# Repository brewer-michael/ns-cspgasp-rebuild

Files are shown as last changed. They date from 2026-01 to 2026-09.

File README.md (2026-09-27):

# Open Speaker

**An open-source rebuild of the Insignia NS-CSPGASP smart speaker: a voice
assistant and alarm clock for Home Assistant, with speech recognition and AI models
on your own network. Its brain is an ESP32-S3 or a Raspberry Pi Zero 2 W.**

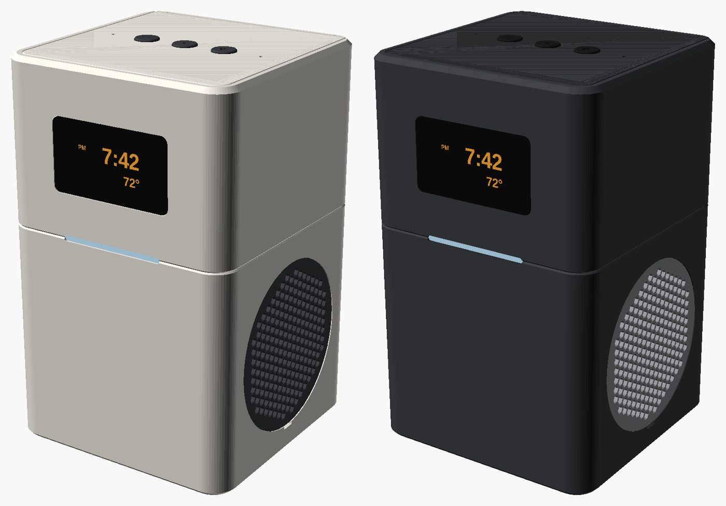
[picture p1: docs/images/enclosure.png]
Open Speaker, light and dark


Google stopped supporting the NS-CSPGASP's Assistant board, and its hardware is
locked down. This project keeps only the two speaker drivers and replaces
everything else with parts you can buy anywhere, in a 3D-printed enclosure on the
original's footprint.

- **Voice control through Home Assistant**: "Okay Nabu, turn off the kitchen
  lights".
- **Your models, on your network**: Whisper or Speech-to-Phrase for speech
  recognition, Ollama, llama.cpp or any OpenAI-compatible server for the
  conversation, Piper or Kokoro for the voice. Nothing leaves your home unless
  you choose a cloud service.
- **Light on the speaker**: only the wake word (microWakeWord) runs on the speaker.
  Speech recognition runs elsewhere.
- **A clock first**: the display always shows the time and temperature, like the
  original, and the alarm rings even when the network is down.
- **Stereo**, two MAX98357A amplifiers into the original drivers, in a tuned
  bass chamber.
- **Physical buttons** for volume, talk/stop/snooze and microphone mute. Status
  light in the waist.

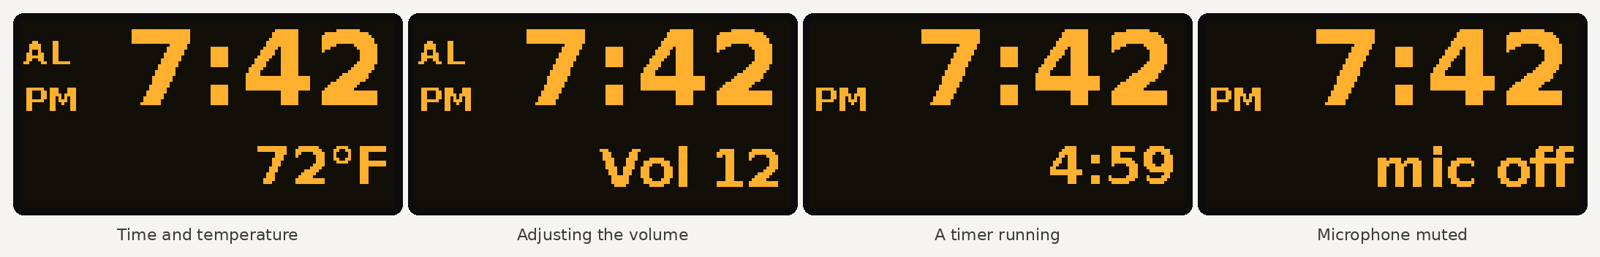
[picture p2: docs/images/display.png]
The clock face: time, AL/PM, and the temperature slot showing the temperature, the volume, a timer or "mic off"


## How it works

```
 Open Speaker                                      your network
 ┌──────────────────────────────┐
 │ 2 × INMP441 mics ─► wake word │   voice    ┌──────────────────────────────┐
 │ (microWakeWord)               │ ─────────► │ Home Assistant Assist pipeline│
 │                               │            │  (Pi: or your own servers):   │
 │ clock, alarm, volume,         │   reply    │  speech-to-text  (Whisper)    │
 │ mute: on the speaker          │ ◄───────── │  language model  (Ollama)     │
 │                               │            │  text-to-speech  (Piper)      │
 │ 2 × MAX98357A ─► 2 drivers    │            └──────────────────────────────┘
 │ OLED clock, LEDs, buttons     │ ◄── Home Assistant automations
 └──────────────────────────────┘
```

## Two brains

Everything except the brain is the same: drivers, amplifiers, microphones, display,
LEDs, buttons, enclosure and wiring. Pick one:

| | ESP32-S3 (default) | Raspberry Pi Zero 2 W |
|---|---|---|
| Board | ESP32-S3-DevKitC-1-N8R8, $15 | Pi Zero 2 WH and a microSD card, about $27 |
| Software | ESPHome: [`esphome/`](esphome/) | The `open-speaker` Linux service: [`firmware/`](firmware/) |
| Needs Home Assistant | Yes | No: it can also talk to your speech and AI servers directly |
| Timers and alarms | Timers by voice through Home Assistant; the alarm clock rings from the speaker's clock | Handled on the speaker, by voice, even when the network is down |
| Automations | ESPHome entities and actions | An HTTP API |
| Availability | Easy to buy | Often out of stock in 2026 |

The ESP32-S3 is the default because you can buy it everywhere and it is the
simplest to run. The Pi does more on its own.

## Hardware

| | |
|---|---|
| Brain | ESP32-S3-DevKitC-1 or Raspberry Pi Zero 2 W |
| Audio out | 2 × MAX98357A I2S class-D amplifiers, 3 W each, into the original 4 Ω drivers |
| Audio in | 2 × INMP441 I2S MEMS microphones |
| Display | 1.3" 128 × 64 OLED (on the Pi also a 2.42" OLED or a TM1637 7-segment display) |
| Controls | 4 tactile buttons, 3 WS2812B status LEDs |
| Power | 5 V 3 A over USB-C |
| Enclosure | 100 × 100 × 160 mm, PETG, no supports; ported bass chamber |

About $75 in parts per speaker with the ESP32-S3 ($87 with the Pi), or about $215
for the first one, because many parts come in packs: see the
[bill of materials](docs/BOM.md), with a link for every part. To shop, open
[docs/shopping-list.html](docs/shopping-list.html) in a browser.

## Getting started

1. **Build**: [docs/ASSEMBLY_GUIDE.md](docs/ASSEMBLY_GUIDE.md): teardown, wiring,
   testing on the desk, enclosure.
2. **Install**:
   - ESP32-S3: flash it with ESPHome, see [esphome/README.md](esphome/README.md).
   - Pi: on Raspberry Pi OS Lite (64-bit):

     ```sh
     git clone -b v2 https://github.com/brewer-michael/ns-cspgasp-rebuild.git
     sudo ns-cspgasp-rebuild/scripts/install.sh
     ```

3. **Connect**: [Home Assistant](docs/HOME_ASSISTANT.md). On the Pi, you can also
   use [your own speech and AI servers](docs/LOCAL_AI.md) directly;
   `sudo open-speaker doctor` checks the whole setup.

## Repository

| Path | |
|---|---|
| [`esphome/`](esphome/) | The ESP32-S3 brain: ESPHome configuration and sounds |
| [`firmware/`](firmware/) | The Raspberry Pi brain: the `open-speaker` Python package and its tests |
| [`hardware/enclosure/`](hardware/enclosure/) | Parametric OpenSCAD enclosure, export script |
| [`hardware/schematics/gpio_pinout.md`](hardware/schematics/gpio_pinout.md) | Wiring for both brains |
| [`hardware/speaker_specs/`](hardware/speaker_specs/) | Measuring the salvaged drivers |
| [`scripts/`](scripts/) | Installer for the Pi, and checks that keep the docs and sounds in step |
| [`config/`](config/) | ALSA, boot configuration and systemd unit (used by the installer) |
| [`server/`](server/) | Docker Compose for Whisper, Piper and Ollama |
| [`docs/`](docs/) | Build guide, BOM and shopping list, Home Assistant and local AI guides |
| [`insignia_ns_cspgasp_rebuild/`](insignia_ns_cspgasp_rebuild/) | Archive: the first plan, which reused the original case and display board |

Both brains live side by side on one branch, and CI builds and checks both on
every push.

## Status

- **Pi software**: complete for the features above and covered by unit tests. They
  run against fake audio devices, fake GPIO and fake Home Assistant and Wyoming
  servers.
- **ESP32-S3 software**: the ESPHome configuration validates and CI compiles it;
  it hasn't run on a speaker yet.
- **Enclosure**: modelled and checked in OpenSCAD for printability, part
  clearances and assembly order, with either brain. It hasn't been printed yet,
  and the driver dimensions are estimates from the teardown photos until measured.
- **Electronics**: the wiring follows the parts' datasheets; the full build is
  still to be bench tested.

The background and design decisions are in
[NS-CSPGASP_Rebuild_Plan.md](NS-CSPGASP_Rebuild_Plan.md).

## License

MIT, see [LICENSE](LICENSE).

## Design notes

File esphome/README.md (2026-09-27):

# ESP32-S3 brain (ESPHome)

[`open-speaker.yaml`](open-speaker.yaml) runs the speaker on an ESP32-S3 with
[ESPHome](https://esphome.io). The ESP32-S3 listens for the wake word itself and
Home Assistant's Assist pipeline does the rest: speech-to-text, the assistant and
text-to-speech. Point that pipeline at your own servers (Whisper, Piper, Ollama)
or at a cloud service.

The rest of the hardware is the same as the Raspberry Pi build. For the Pi's
software, see [`../firmware`](../firmware).

## What you need

- An **ESP32-S3-DevKitC-1 with 8 MB flash and 8 MB PSRAM** (N8R8), wired as in
  [gpio_pinout.md](../hardware/schematics/gpio_pinout.md#esp32-s3). It sits on the
  printed `esp32_cradle` in the enclosure.
- **Home Assistant** with the ESPHome integration and an Assist pipeline
  ([HOME_ASSISTANT.md](../docs/HOME_ASSISTANT.md#esp32-s3-speaker)).
- **ESPHome 2026.9 or newer**: the ESPHome Device Builder in Home Assistant, or
  `pip install esphome` on a computer.

## Install

1. In the ESPHome Device Builder, create a new device. Replace its YAML with the
   following, keeping the API encryption key it generated:

   ```yaml
   substitutions:
     name: open-speaker
     friendly_name: Open Speaker
     temperature_entity: weather.forecast_home

   packages:
     open_speaker: github://brewer-michael/ns-cspgasp-rebuild/esphome/open-speaker.yaml@v2

   wifi:
     ssid: !secret wifi_ssid
     password: !secret wifi_password

   api:
     encryption:
       key: "..."
   ```

2. Unplug the speaker's power supply, then connect either of the DevKitC's USB-C
   ports to the computer. **Never power the DevKitC from its USB port and the
   5 V wire at the same time.**
3. Choose **Install**, then **Plug into this computer**. Later updates go over
   Wi-Fi.
4. Home Assistant discovers the speaker; add it under **Settings → Devices &
   services**. On the device page, pick the Assist pipeline it should use.

For several speakers, give each its own `name` and `friendly_name`.

Without the Device Builder, from a copy of this repository:

```sh
esphome run esphome/open-speaker.yaml
```

With no Wi-Fi details the speaker opens a hotspot named after it. Join it to
enter your Wi-Fi, or use Improv over USB at [web.esphome.io](https://web.esphome.io).

## Settings

Set these under `substitutions:` in your own YAML.

| Setting | Default | |
|---|---|---|
| `wake_word` | `okay_nabu` | Also `hey_jarvis`, `hey_mycroft` or `alexa` |
| `temperature_entity` | `weather.forecast_home` | Any weather or temperature sensor entity |
| `temperature_attribute` | `temperature` | Set it to `""` for a sensor entity |
| `temperature_unit` | `°` | For example `°F` |
| `clock_24h` | `false` | `true` for a 24-hour clock |
| `night_start_hour`, `night_end_hour` | `22`, `7` | The display and the light dim between these hours |
| `mic_gain` | `4` | Raise it if the wake word needs you to speak up, 1 to 64 |
| `*_pin` | see the file | Only if your wiring differs |

## In Home Assistant

| Entity or action | |
|---|---|
| Media player | Volume, announcements and music |
| Mute microphone | The back button toggles it too |
| Alarm, Alarm time, Alarm days | The alarm clock. It rings from the speaker's own clock, so it works while Home Assistant is down. |
| Stop ringing | Stops an alarm or timer |
| Wake sound | The chime when it starts listening |
| `esphome.<name>_ring_alarm`, `esphome.<name>_stop_ringing` | Actions for automations |

Timers work by voice ("set a timer for ten minutes"). Home Assistant keeps track of
them and the speaker counts down on the display and rings.

## Differences from the Raspberry Pi build

- It needs Home Assistant. It can't talk to Wyoming or OpenAI-compatible servers
  directly, so connect those to Home Assistant's pipeline instead.
- Timers need Home Assistant to be running. Alarms don't.
- You can't set alarms by voice yet. Set them in Home Assistant, or write an
  automation that sets **Alarm time**.
- It listens with the left microphone only.
- There's no HTTP API. Automations use the entities and actions above.

## For developers

- Validate: `esphome config esphome/open-speaker.yaml`.
- Build from your working copy instead of GitHub:
  `esphome -s sounds sounds compile esphome/open-speaker.yaml`.
- The sounds in [`sounds/`](sounds) are the Linux firmware's built-in sounds.
  After changing one there, run `python3 scripts/make_esphome_sounds.py`.
- CI builds this file on every push.

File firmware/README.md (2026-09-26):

# open-speaker

The software for [Open Speaker](../README.md): a voice assistant and alarm clock
for a Raspberry Pi Zero 2 W, for Home Assistant or your own speech and language
model servers.

It runs as one asyncio process: microphone capture, the wake word, the voice
pipeline, timers and alarms, the display, LEDs, buttons and an HTTP API.

## Install

On the speaker, use the [installer](../scripts/install.sh). It also sets up the
sound card, the configuration and the systemd service. To install the package
alone:

```sh
python3 -m venv --system-site-packages venv
venv/bin/pip install ".[pi]"        # on a Raspberry Pi
venv/bin/pip install ".[dev]"       # on a PC, for development
```

Python 3.11 or newer. Extras: `pi` (microWakeWord, microVAD, GPIO, I2C, display),
`openwakeword`, `dev` (pytest, ruff).

## Commands

```
open-speaker [--config FILE] [--debug] COMMAND

  run              run the speaker (what the service does)
  check-config     validate the configuration and print it with defaults filled in
  example-config   print a commented example configuration
  doctor           check audio devices, microphones, display, LEDs, GPIO and servers
  test-speaker     play the built-in sounds [--say "text" to try text-to-speech too]
  test-mic         show microphone levels [--seconds N] [--save file.wav]
  say TEXT         speak TEXT through the voice pipeline
  ask TEXT         send a typed request to the assistant and play the answer
```

The configuration file is `/etc/open-speaker/config.yaml`. Every option is
explained in [`open_speaker/data/config.example.yaml`](open_speaker/data/config.example.yaml).
Values like `${HA_TOKEN}` come from the environment. The service gets them from
`/etc/open-speaker/secrets.env`, and the commands read the `secrets.env` next to
the configuration file themselves.

## Code map

| Module | |
|---|---|
| `app.py` | `Speaker`: state machine that ties everything together |
| `pipeline/` | Home Assistant Assist pipeline over WebSocket, or the local pipeline (STT, agents, TTS) |
| `wake/`, `vad.py` | microWakeWord / openWakeWord on the device, or a Wyoming wake word server; end-of-speech detection |
| `stt/`, `tts/`, `agents/` | Wyoming and OpenAI-compatible clients; Home Assistant and OpenAI-compatible (Ollama, llama.cpp, ...) conversation agents |
| `homeassistant.py` | Home Assistant REST and WebSocket client |
| `intents.py`, `timers.py` | Commands handled on the speaker; timers and alarms that survive restarts |
| `audio/` | `arecord`/`aplay` capture and playback, volume and ducking, built-in sounds |
| `hardware/`, `ui.py` | Buttons (gpiozero), OLED and TM1637 displays, WS2812B over SPI, the clock face |
| `api.py` | HTTP API for Home Assistant automations |
| `config.py`, `factory.py`, `cli.py`, `doctor.py` | Configuration, wiring up, command line, self-test |

## Development

```sh
pip install -e ".[dev]"
pytest
ruff check . && ruff format --check .
```

The tests use fake audio devices, fake GPIO pins and fake Home Assistant and
Wyoming servers, so they run on an ordinary PC; no Raspberry Pi needed.

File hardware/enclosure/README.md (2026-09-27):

# Enclosure

Front, light and dark

A 100 × 100 × 160 mm tower, close to the footprint of the NS-CSPGASP it replaces
(96 × 96 × 151.6 mm):

- **Bass chamber** (lower 84 mm): the two salvaged drivers fire left and right
  behind round press-fit grilles. The chamber is tuned by a port in the back panel,
  or uses a passive radiator, or stays sealed.
- **Waist groove** around the body. The status LEDs shine through it at the front
  as a thin line of light.
- **Head**: the clock display sits behind a flush smoked window. The top plate has
  three buttons and two microphones and no visible fasteners.
- **Back panel**: the only screwed-on part. It carries the port, USB-C power and the
  microphone mute button, and it locks the top plate in place. Take it off to reach
  the brain: its USB port on the ESP32-S3, its microSD card on the Pi.

Everything is in [`main_body.scad`](main_body.scad) (OpenSCAD 2021.01 or newer). It
is parametric: the dimensions of your drivers, the display type and the bass
option are all settings at the top of the file.

| Exploded | Section | Back |
|---|---|---|
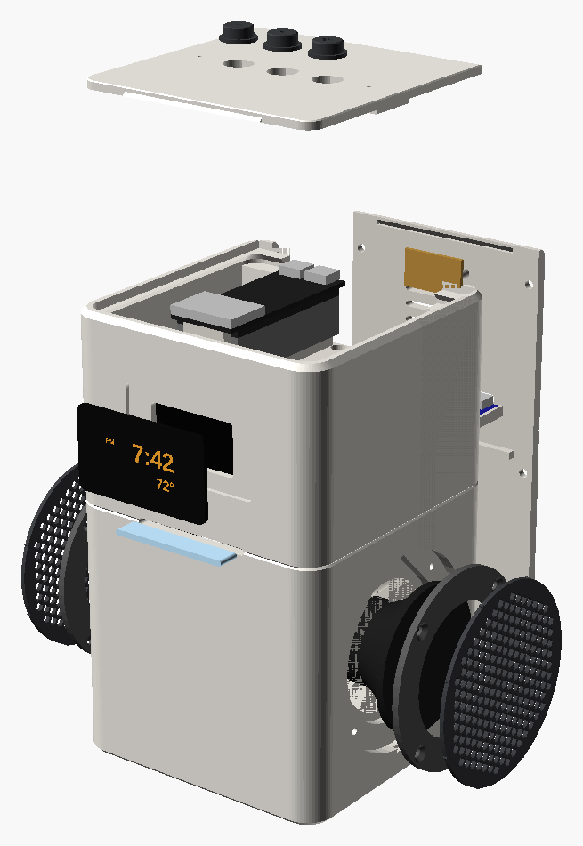
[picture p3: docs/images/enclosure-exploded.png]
Exploded
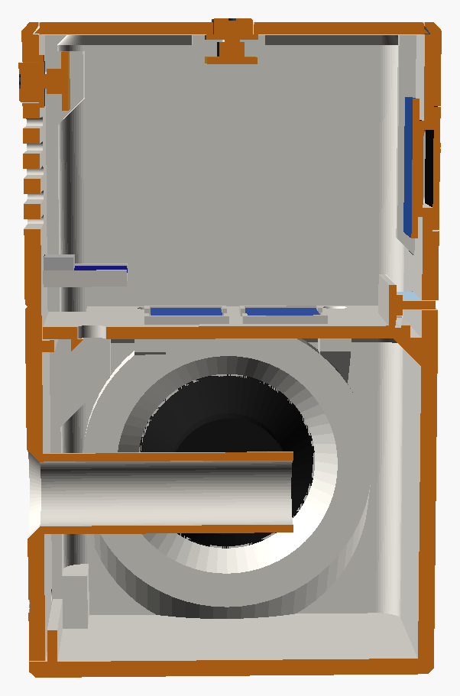
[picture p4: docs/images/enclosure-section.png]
Section
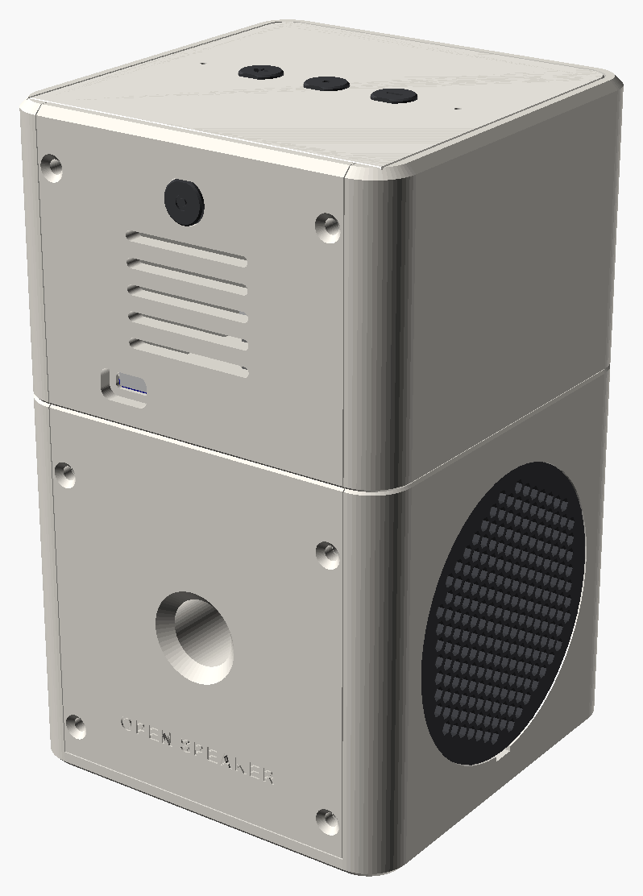
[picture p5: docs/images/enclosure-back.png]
Back
|  |  |  |

## Before you print: measure the drivers

The driver values in the file are estimates taken from the teardown photos. Take
the drivers out of the original unit, fill in
[`../speaker_specs/measurements.md`](../speaker_specs/measurements.md), then set:

| Parameter | What to measure |
|---|---|
| `speaker_frame_diameter` | Outside diameter of the frame (the flange at the front) |
| `speaker_cone_diameter` | Cone plus rubber surround: the part that moves and must stay uncovered |
| `speaker_basket_diameter` | Widest part *behind* the flange. It passes through the side wall. |
| `speaker_flange_thickness` | Thickness of that front flange |
| `speaker_depth` | Front of the flange to the back of the magnet |
| `speaker_mount` | `clamp` (default): a printed ring clamps the flange, so any round driver works. `holes`: screws go through the frame's own holes. Set `speaker_hole_circle`, `speaker_hole_count` and `speaker_hole_angle` too. |

The model checks itself: OpenSCAD stops with a message if the drivers would hit the
floor, the deck, the port or each other.

Other settings you might change:

| Parameter | Default | Options |
|---|---|---|
| `brain` | `esp32_s3` | `pi_zero_2w`. The deck is the same for both; the ESP32-S3 adds the printed `esp32_cradle`. |
| `display_type` | `oled_1_3` | `oled_2_42` (larger window, SSD1309) or `tm1637` (4-digit 7-segment, Pi only) |
| `bass_mode` | `port` | `passive_radiator` (set `radiator_*` to your radiator) or `sealed` |
| `port_tuning_hz` | 120 | The port length is calculated from the chamber volume |
| `grille_pattern` | `hex` | `rings` |
| `fit` | 0.25 mm | Clearance between printed parts. Raise it if parts bind. |

On every render OpenSCAD prints the chamber volume and the port length, e.g.
`Port: 16 mm x 65 mm, tuned to ~120 Hz`.

## Export

```sh
./export.sh                                   # STLs into ./stl
./export.sh -D speaker_frame_diameter=53      # with your measurements, no file edits
./export.sh --images                          # also refresh docs/images/enclosure-*.png
```

Or open `main_body.scad` in OpenSCAD, choose a part in the Customizer, then render
(F6) and export.

## Printed parts

PETG throughout: it is tougher and damps vibration better than PLA. Use 0.2 mm
layers, 4 perimeters and 40% gyroid infill. **No supports are needed.** Overhangs
are 45 degrees or less, and horizontal holes have pointed or bridged tops.

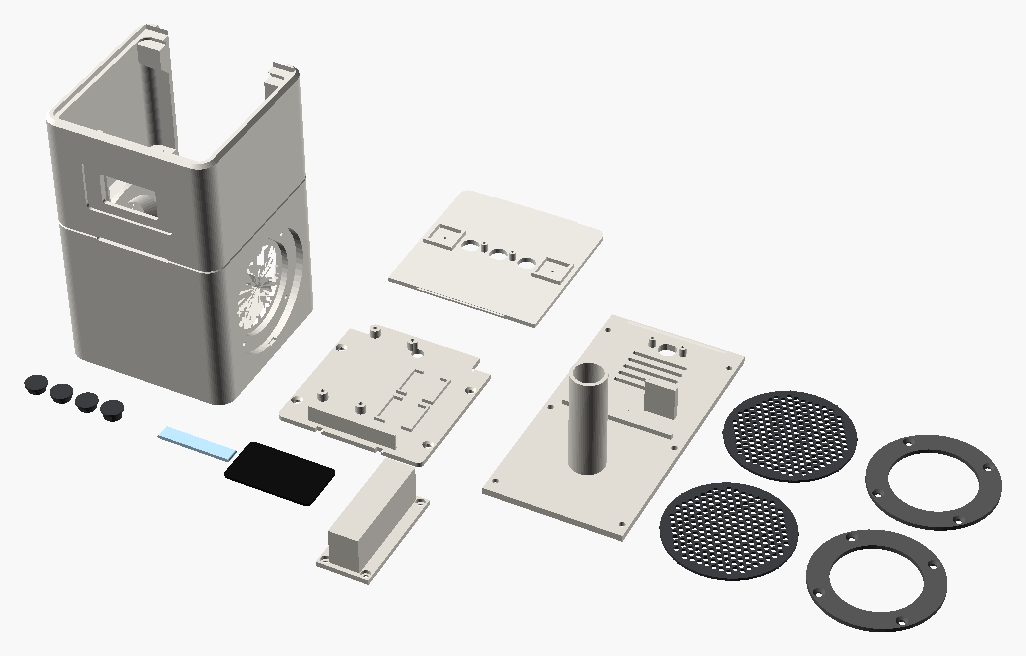
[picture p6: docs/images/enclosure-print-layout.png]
Print layout


| Part | Qty | Orientation | Notes |
|---|:-:|---|---|
| `body` | 1 | Upright, bottom on the bed | ~300 g, needs 160 mm of Z height. Enable bridging: the tops of the display opening and light slot are bridges. |
| `back_panel` | 1 | Outside face down | Port tube, USB-C shelf and mute button bosses point up |
| `deck` | 1 | As exported | Chamber lid; carries the brain, the amplifiers and the LED strip |
| `esp32_cradle` | ESP32-S3 only | As exported | Holds the ESP32-S3-DevKitC-1 on the deck's standoffs |
| `top_plate` | 1 | Upside down (exported that way) | The bed texture becomes the top surface |
| `grille` | 2 | Outside face down | Crush ribs on the rim make it a press fit |
| `clamp_ring` | 2 | Countersinks up | Not needed with `speaker_mount = "holes"` |
| `caps` | 1 set | Tops on the bed (exported that way) | −, •, + for the top and ○ for mic mute. D-shaped so they can't turn. |
| `diffuser` | 1 | Flat | **White or natural** PETG: carries the LED light to the slot |
| `window` | optional | Flat | Only if you can't get acrylic (see below) |
| `port_plug` | optional | Flange down | Turns a ported back panel into a sealed box |

About 450 g of filament in total.

## Other parts

Links and prices are in the [bill of materials](../../docs/BOM.md).

| Item | Qty | Use |
|---|:-:|---|
| M3 brass heat-set inserts, 5.7 mm long (ruthex), in 4.0 mm holes | 6 | Back panel pillars |
| M3 × 8 countersunk hex socket (ISO 10642) | 6 | Back panel |
| M3 × 8 countersunk | 8 | Clamp rings. They cut their own thread in the side walls. |
| M3 × 10 countersunk | 4 | Deck to the side blocks (self-tapping) |
| M2.6 × 6 self-tapping pan head, or M2.5 × 6 | 4 | The Pi, or the ESP32-S3's cradle, to the deck standoffs |
| M2 × 6 self-tapping | 4 | Switch boards (top plate and back panel) |
| Omron B3F-1000 tactile switches, 6 × 6 mm | 4 | Through-hole, 4.3 mm from the board to the top of the plunger (`switch_height`) |
| Perfboard, 2.54 mm pitch | 50 × 12 mm and 24 × 14 mm | The three top switches sit 7 holes apart |
| Smoked acrylic, 1/16" (1.5–1.6 mm) | 51.5 × 29.5 mm, 2.75 mm corners | Display window (68 × 40 for the 2.42" OLED). Set `window_thickness` to your sheet's thickness. |
| Closed-cell foam tape, 1 mm thick, 5–6 mm wide | ~1 m | Seals the chamber: deck ledge, back frame, panel rib, behind the driver flanges |
| 3M Bumpon SJ5312 feet, 12.7 × 3.6 mm | 4 | Recesses in the bottom |
| Polyester fibre fill | a handful | Loosely in the chamber |

**Display window.** A laser-cutting service or a local makerspace can cut the
acrylic. You can also score it with a knife, snap it and file the corners. Behind
smoked acrylic the display disappears when it is dark, like the original's. If you
have to print the window instead, set `window_thickness = 1.2` and print it in clear
PETG at 100% infill. The digits will look softer.

## Assembly

The clearances between all the parts have been checked in the model, and so have
the paths the deck and the display take on their way in.

1. **Inserts.** Press the six M3 inserts into the pillars beside the back opening
   (soldering iron at about 220 °C).
2. **Deck.** Screw the brain to the standoffs:
   - **ESP32-S3:** screw the `esp32_cradle` down (the screw heads sit below its
     surface). Set the DevKitC on its rib, pins down and USB ports towards the
     back, and hold it with a dab of hot glue at each end; it peels off again.
     The harness plugs onto its pins from below.
   - **Pi:** microSD slot towards the back.

   Fix the amplifiers in their cradles with a dab of hot glue and stick the 3-LED
   strip to the fin, LEDs facing forward. Thread two pairs of speaker wire (~15 cm)
   down through the wire hole. Run foam tape along the top of the chamber ledge.
   Lower the deck into the body and fix it with 4 × M3 × 10. Seal the wire hole
   with hot glue.
3. **Display.** Solder the wires on, then slide the module down its rails from the
   top, glass facing the window. Press the acrylic window into its recess from the
   front. A few dots of E6000 on the recess floor, clear of the display area, hold
   it.
4. **Light.** Push the diffuser into the slot from the front until it touches the
   LEDs. Its front face sits 0.6 mm back, in the waist groove. A drop of glue holds it.
5. **Drivers.** Reach through each side opening and pull out that side's wire pair.
   Solder it to the driver, red to +. Put a loose handful of fibre fill into the
   chamber. Set the driver into its seat with a foam ring behind the flange. Fit
   the clamp ring (4 × M3 × 8), then press the grille on. To take a grille off
   again, lever it out at the notch underneath.
6. **Top plate.** Drop the caps into their holes. Screw the switch strip onto the
   two bosses (2 × M2 × 6). Glue the INMP441 boards into their pockets with the
   sound hole over the port; a small foam ring around the port seals it. Wire
   everything to the brain. Slide the plate's front tongue into the groove behind the
   front wall, then lower the back of the plate.
7. **Back panel.** Glue the USB-C breakout onto its shelf, receptacle against the
   panel. Screw on the mute switch board with its cap. Run foam tape along the
   body's frame beside and below the chamber opening, and along the panel's rib.
   Slide the panel in: its groove catches the top plate's rear tongue and its rib
   slides under the deck. Fix it with 6 × M3 × 8.
8. **Feet.** Stick the four bumpers into the recesses underneath.

Wiring is in [`../schematics/gpio_pinout.md`](../schematics/gpio_pinout.md). The
complete build, from the teardown to software, is in
[`../../docs/ASSEMBLY_GUIDE.md`](../../docs/ASSEMBLY_GUIDE.md).

## Design notes

- **Why the drivers mount from outside.** The original's drivers are clamped
  between the halves of its plastic box. They may have no screw holes, so the
  default mount clamps the flange with a ring and fits any round driver. The seat
  behind the flange flares out at 45 degrees, so the back of the cone is never boxed
  in, and the flare prints without support.
- **One shared chamber** for both drivers, about 0.54 L net. The earlier plan
  divided it. A single tuned volume gives more bass from drivers this small, and at
  low frequencies both drivers play the same signal anyway.
- **Airtight where it matters.** The chamber leaks only through the port. The deck
  seals on a 7 mm ledge; the back panel seals on foam tape below the deck line.
  Above the deck line, the panel's frame is the hard stop that sets how far the
  foam compresses.
- **No visible fasteners on the front, sides or top.** Screws hide under the
  grilles, and the top plate is held by tongues. The six countersunk screws are all
  on the back.
- **Heat.** The brain sits on the deck under the vents in the back panel. The vents
  open into the head, which is sealed off from the chamber.

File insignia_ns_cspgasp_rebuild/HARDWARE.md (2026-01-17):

# Hardware Interface Guide (Insignia NS-CSPGASP)

## ⚠️ SAFETY WARNING ⚠️
-   **Voltage Logic Levels:** The "Condor" logic (SDA/SCL) is likely **3.3V**, but verify!
-   **Power Input:** The device power rail might be **5V** or **12V**. Check the label on the power brick and measure the internal "Red/Black" cable with a multimeter.
-   **Ribbon Cables:** These are fragile. Unlock connectors before pulling cables.

## 1. Top Board ("Condor Touch Board") & Front Display
The upper daughterboard contains the Capacitive Touch sensors. Crucially, **it also acts as a pass-through** for the signals going to the **Front LED Display** (visible in `IMG_2901.jpg`).

### Interface Topology
`Main Board` --(Ribbon Cable)--> `Top Board` --(Internal Routing)--> `Front LED Display` & `Microphones`

### Connection Point
-   **Target:** The Ribbon Cable (FPC) connector labeled **CN4**.
-   **Function:** Intercepting this *single cable* grants access to Touch, Display, and Microphones.
-   **Requirement:** A **Custom FPC Interface HAT**.
    -   Since no off-the-shelf HAT exists for this specific pinout, you must build one.
    -   **Parts:**
        1.  **Proto Zero HAT** (PCB that fits on Pi GPIO).
        2.  **20-Pin 0.5mm FPC Breakout Board**.
    -   **Assembly:** Solder the Breakout Board flat onto the Proto HAT and wire signals to GPIOs.
    -   **Pin Count:** **20 Pins** (Verified).
    -   **Pitch:** **0.5mm** (Verified).

### Pinout (Hypothetical - Requires Probing)
> [!IMPORTANT]
> **Safety First: Do NOT inject voltage yet!**
> The safest way to identify pins is to "Sniff" the original board while it is running.

### Pinout & Schematics
> [!IMPORTANT]
> **See `SCHEMATICS.md` for the precise ASCII Pinout Maps.**
> Use that document to verify every wire connection.

## 2. Component Analysis (Understanding the Hardware)

### The "Condor" Main Board
-   **Role:** Power management & Audio Amplification.
-   **Key Findings:**
    -   **Twin Mono Block:** The presence of **Two 4R7 Inductor pairs** + **Two LPS A6711 Chips** confirms a high-quality "Twin Mono" Stereo architecture.
    -   **Bypass Strategy:** We are completely removing the `S810BB` System-on-Module (the original "Brain") and replacing it with the Pi Zero 2 W.

### The Probing Strategy
**Goal:** Identify `VCC` (Power) and `GND` lines on the ribbon cable without frying anything.
1.  **Don't Probe the Pads:** The 0.5mm pads on the Top Board are too small.
2.  **Use the Breakout:** Plug the ribbon cable into your FPC Breakout Board. Probe the large DIP holes.
3.  **Trace GND:** Find the block of 4 contiguous pins. That is Ground.
4.  **Find VCC:** The pin measuring 3.3V or 5V relative to Ground is your power line.

## 3. Assembly Guide: "The Sandwich"
**Goal:** Create a single, solid unit that snaps onto the Pi.

### Step 1: Physical Mounting
1.  Stick the **FPC Breakout Board** to the center of the **Proto HAT** using foam tape.
2.  Solder short jumper wires from the Breakout pads to the nearest Proto HAT holes.

### Step 2: Input Module (Microphones & Controls)
*Refer to `SCHEMATICS.md` -> Section 2 for the FPC Pinout.*
-   **Connect:** `SDA`, `SCL`, `BCLK`, `LRC`, `DIN` (Mic Data), `GND`, `3.3V`.
-   **Note:** `BCLK` and `LRC` are shared buses. You will solder two wires to these pins (one from FPC, one going to Amps).

### Step 3: Output Module (Twin Stereo Amps)
*Refer to `SCHEMATICS.md` -> Section 3 for the Amp Wiring.*
**Logic:** We use the `SD_MODE` resistor method to separate Left/Right channels.

1.  **Amp 1 (Left):** Connect `SD_MODE` -> **5V** directly.
2.  **Amp 2 (Right):** Connect `SD_MODE` -> **5V** via **390kΩ Resistor**.
3.  **Wires:** Run 4 wires from the Pi (VSYS, GND, BCLK, LRC, DIN) to *both* amps (Daisy chain or Y-split).

### Step 4: Speaker Connection
**Do NOT connect speakers to the Pi.**
-   Trace the Red/Black wires from the **Left Speaker** -> Screw into **Amp 1**.
-   Trace the Red/Black wires from the **Right Speaker** -> Screw into **Amp 2**.

## 4. Power & Final Check
-   **Voltage Check:** Before plugging into the Pi, verify the Breakout Board `VCC` is getting 3.3V (Logic) and Amps are getting 5V (Power).
-   **Inductor Note:** The original board used a "Twin Mono Block" design (2 inductors per channel). By using two MAX98357A amps, we are faithfully restoring this high-quality topology.

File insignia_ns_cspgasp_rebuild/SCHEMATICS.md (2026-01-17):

# System Schematics: Insignia NS-CSPGASP Rebuild

**Reference Document.** Use this for verifying pin locations and wire connections.

## 1. Raspberry Pi Zero 2 W (GPIO Header)
**View:** Top Down (Pins facing you).
**Orientation:** SD Card slot is LEFT. USB ports are BOTTOM.

```text
       [  5V ]  [  5V ]  (Pin 2/4 = Power for Amps)
         |        |
    +----v--------v----+
    |  o  o :: o  o  |  Pin 1 (3.3V) - Power for FPC Logic
    |  o  o :: o  o  |  Pin 3  (SDA) - FPC SDA
    |  o  o :: o  o  |  Pin 5  (SCL) - FPC SCL
    |  o  o :: o  o  |
    |  o  o :: o  o  |  Pin 9  (GND) - Common Ground
    |  o  o :: o  o  |
    |  o  o :: o  o  |
    |  o  o :: o  o  |
    |  o  o :: o  o  |
    |  o  o :: o  o  |  Pin 18 (BCLK)- SHARED: FPC + Amp 1 + Amp 2
    |  o  o :: o  o  |  Pin 20 (GND)
    |  o  o :: o  o  |  Pin 19 (LRC) - SHARED: FPC + Amp 1 + Amp 2
    |  o  o :: o  o  |  Pin 21 (DOUT)- Amp 1 + Amp 2 (Audio Out)
    +------------------+
          (USB Ports)
```

## 2. 20-Pin FPC Breakout Board (Input Module)
**View:** Top Down (Connector facing UP).
**Pitch:** 0.5mm
**Note:** Verify Pin 1 (Triangle) on your board.

```text
[   RIBBON CABLE ENTRY   ]
+------------------------+
| 1  2  3  4  5 ... 20   |
+--+--+--+--+--+---------+
   |  |  |  |  |
   |  |  |  |  +-- Pin 5 (GND) -> Pi GND
   |  |  |  +----- Pin 4 (RES) -> (Not Connected)
   |  |  +-------- Pin 3 (SDA) -> Pi Pin 3 (SDA)
   |  +----------- Pin 2 (SCL) -> Pi Pin 5 (SCL)
   +-------------- Pin 1 (INT) -> Pi GPIO 27 (Optional)

[ Crucial Signals ]
Pin 9  (BCK1)   -> Pi Pin 12 (GPIO 18 / BCLK) [*Shared*]
Pin 10 (FS1)    -> Pi Pin 35 (GPIO 19 / LRC)  [*Shared*]
Pin 11 (MIC_SD) -> Pi Pin 38 (GPIO 20 / DIN)  [Mic Data In]
Pin 20 (VCC)    -> Pi 3.3V / 5V (Verify Voltage!)
```

## 3. Stereo Amplifier Module (MAX98357A Pair)
**View:** Top Down (Chip up).

**Left Channel Amp (Amp 1)**
```text
      [ VIN ] <--- 5V (Pi Pin 2/4)
      [ GND ] <--- GND
      [ DIN ] <--- Pi Pin 40 (GPIO 21 / DOUT)
      [BCLK ] <--- Pi Pin 12 (GPIO 18 / BCLK)
      [ LRC ] <--- Pi Pin 35 (GPIO 19 / LRC)
      [ GAIN]      (Float = 9dB default)
      [ SD  ] <=== WIRE ===> [ VIN / 5V ]  (Threshold > 1.4V = LEFT)
```

**Right Channel Amp (Amp 2)**
```text
      [ VIN ] <--- 5V (Pi Pin 2/4)
      [ GND ] <--- GND
      [ DIN ] <--- Pi Pin 40 (GPIO 21 / DOUT)
      [BCLK ] <--- Pi Pin 12 (GPIO 18 / BCLK)
      [ LRC ] <--- Pi Pin 35 (GPIO 19 / LRC)
      [ GAIN]      (Float = 9dB default)
## 4. Internal Connections (Reference Only)
**Front LED Display (10-Pin 1.0mm)**
*This cable connects the Top Board (Daughter) to the Front Face.*
-   **Connection:** Logic is handled by the Top Board.
-   **Control:** The Pi controls this indirectly via the main **20-Pin FPC** (likely `SDA`/`SCL`).
-   **Debugging:** You may need the **10-Pin Extension Cable** to keep this connected while the Top Board is removed for testing.

## 5. Power Distribution Map (Star Topology)

**WARNING:** Do NOT power the system via the Pi's Micro-USB port alone. The Amps + Display + Pi will exceed the current limit. Use a dedicated 5V rail.

### 5.1 The Logic
Instead of daisy-chaining, we use a **Star Topology** where all high-current devices connect directly to the main 5V source.

```
[DC Input Jack] (12V or 5V)
      │
      ▼
[Buck Converter] (Step-Down Regulator)
   Input: 12V (or 5V if bypassing)
   Output: 5.0V (Adjusted to precise 5.1V is ideal)
      │
      ▼
[Terminals / Shared 5V Rail] ════════════════════════╗
      │                    │                    │    │
      ▼                    ▼                    ▼    ▼
[Pi Zero 2 W]        [Amp 1 Left]         [Amp 2 Right]
   (Pin 2/4)            (VIN)                (VIN)
      │                    │                    │
      ▼                    ▼                    ▼
   [GND Rail] ═══════════════════════════════════════╝
```

### 5.2 Wiring Guide (5V Source)
| Component | Wire Color | Connect To |
| :--- | :--- | :--- |
| **Pi Zero 2 W** | Red | **Pin 2 (5V)** *Directly* |
| | Black | **Pin 6 (GND)** |
| **MAX98357A (Left)** | Red | **Shared 5V Rail** |
| | Black | **Shared GND Rail** |
| **MAX98357A (Right)** | Red | **Shared 5V Rail** |
| | Black | **Shared GND Rail** |
| **Top Board** | TBD | **Shared 5V Rail** (Verify First!) |

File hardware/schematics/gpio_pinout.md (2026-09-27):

# Wiring

The speaker has one of two brains: an **ESP32-S3** (ESPHome, the default) or a
**Raspberry Pi Zero 2 W** (the Linux firmware). Everything else wires the same way
to either one; only the pins on the brain differ. Each brain has its own pin table
below, and the sections after them apply to both.

The names used in the shared sections:

| Signal | What it is |
|---|---|
| `AMP_BCLK`, `AMP_LRCLK`, `AMP_DOUT` | I2S bit clock, frame clock and data to the amplifiers |
| `MIC_BCLK`, `MIC_LRCLK`, `MIC_DIN` | I2S bit clock, frame clock and data from the microphones |
| `SDA`, `SCL` | I2C to the OLED |
| `LED` | Data to the WS2812B status LEDs |

## ESP32-S3

ESP32-S3-DevKitC-1 (N8R8). Everything is on its **J1** header, the side with the
`5V` pin, and the board is labelled with the GPIO numbers. The pins are the
defaults in [`esphome/open-speaker.yaml`](../../esphome/open-speaker.yaml); change
them with its substitutions.

| GPIO | J1 pin | Signal | Connects to |
|---|:-:|---|---|
| 5V | 21 | Power in | USB-C breakout VBUS (5 V) |
| 3V3 | 1 | 3.3 V out | Microphones, OLED |
| GND | 22 | Ground | Everything |
| GPIO4 | 4 | `AMP_LRCLK` | Both amps `LRC` |
| GPIO5 | 5 | `AMP_BCLK` | Both amps `BCLK` |
| GPIO6 | 6 | `AMP_DOUT` | Both amps `DIN` |
| GPIO7 | 7 | `LED` | WS2812B `DIN` |
| GPIO15 | 8 | `MIC_LRCLK` | Both mics `WS` |
| GPIO16 | 9 | `MIC_BCLK` | Both mics `SCK` |
| GPIO17 | 10 | `MIC_DIN` | Both mics `SD` (shared) |
| GPIO8 | 12 | `SDA` | OLED `SDA` |
| GPIO9 | 15 | `SCL` | OLED `SCL` |
| GPIO11 | 17 | Button | Volume up |
| GPIO12 | 18 | Button | Volume down |
| GPIO13 | 19 | Button | Action: talk / stop / snooze |
| GPIO14 | 20 | Button | Microphone mute (back panel) |

The microphones and the amplifiers each have their own clocks here, because the
ESP32-S3 runs them on separate I2S buses. None of these pins are strapping pins,
and GPIO10 and GPIO18 stay free.

**Power: one source at a time.** The DevKitC takes 5 V on its `5V` pin from the
USB-C breakout. Unplug the speaker's supply before you connect the DevKitC's own
USB port for flashing.

The DevKitC sits pins down on the printed `esp32_cradle`, with its USB ports towards
the back opening. The harness plugs onto its pins from below: use female jumper
housings, as on the Pi.

## Raspberry Pi Zero 2 W

BCM GPIO numbers. The pins match the defaults in `/etc/open-speaker/config.yaml`;
buttons and the display pins can be changed there, and `open-speaker check-config`
refuses conflicting pins. On the Pi, the amplifiers and microphones share one I2S
bus, so `AMP_BCLK` is `MIC_BCLK` and `AMP_LRCLK` is `MIC_LRCLK`.

| GPIO | Pin | Signal | Connects to |
|---|:-:|---|---|
| 5V | 2, 4 | Power in | USB-C breakout VBUS (5 V) |
| 3V3 | 1, 17 | 3.3 V out | Microphones, OLED |
| GND | 6, 9, 14, 20, 25, 30, 34, 39 | Ground | Everything |
| GPIO18 | 12 | `AMP_BCLK` = `MIC_BCLK` | Both amps `BCLK`, both mics `SCK` |
| GPIO19 | 35 | `AMP_LRCLK` = `MIC_LRCLK` | Both amps `LRC`, both mics `WS` |
| GPIO21 | 40 | `AMP_DOUT` | Both amps `DIN` |
| GPIO20 | 38 | `MIC_DIN` | Both mics `SD` (shared) |
| GPIO2 | 3 | `SDA` | OLED `SDA` |
| GPIO3 | 5 | `SCL` | OLED `SCL` |
| GPIO10 | 19 | `LED` (SPI MOSI) | WS2812B `DIN` |
| GPIO17 | 11 | Button | Volume up |
| GPIO27 | 13 | Button | Volume down |
| GPIO5 | 29 | Button | Action: talk / stop / snooze |
| GPIO22 | 15 | Button | Microphone mute (back panel) |
| GPIO12 | 32 | PWM | Volume LED through 220 Ω (optional) |
| GPIO16 | 36 | **Reserved** | Claimed by the sound card overlay: leave unconnected |
| GPIO23 / 24 | 16 / 18 | TM1637 `CLK` / `DIO` | Only if you use the TM1637 display instead of the OLED |

```
                 Pi Zero 2 W header (component side up, pin 1 top left)

        3V3 mics,OLED  [ 1] [ 2]  5V in (USB-C)
             OLED SDA  [ 3] [ 4]  5V
             OLED SCL  [ 5] [ 6]  GND
                       [ 7] [ 8]
                  GND  [ 9] [10]
       volume up (17)  [11] [12]  I2S BCLK (18)
     volume down (27)  [13] [14]  GND
            mute (22)  [15] [16]  (TM1637 CLK, 23)
                  3V3  [17] [18]  (TM1637 DIO, 24)
    LEDs, SPI MOSI(10) [19] [20]  GND
                       [21] [22]
                       [23] [24]
                  GND  [25] [26]
                       [27] [28]
           action (5)  [29] [30]  GND
                       [31] [32]  volume LED (12)
                       [33] [34]  GND
      I2S LRCLK (19)   [35] [36]  reserved (16)
                       [37] [38]  I2S DIN from mics (20)
                  GND  [39] [40]  I2S DOUT to amps (21)
```

## Buttons

Each button connects its GPIO to GND when pressed. Both brains use their internal
pull-ups, so no resistors are needed.

## Amplifiers (2 × MAX98357A)

Both amps get the same I2S signals. The voltage on each amp's `SD` pin picks its
channel:

| `SD` voltage | Output |
|---|---|
| above 1.4 V | left channel |
| 0.77 – 1.4 V | right channel |
| 0.16 – 0.77 V | (left + right) / 2 |
| below 0.16 V | shut down |

The chip pulls `SD` down with 100 kΩ inside.

| Amp pin | Left amp | Right amp |
|---|---|---|
| `VIN` | 5 V | 5 V |
| `GND` | GND | GND |
| `BCLK` / `LRC` / `DIN` | `AMP_BCLK` / `AMP_LRCLK` / `AMP_DOUT` | `AMP_BCLK` / `AMP_LRCLK` / `AMP_DOUT` |
| `GAIN` | not connected (9 dB) | not connected (9 dB) |
| `SD` | straight to `VIN` | resistor to `VIN`, see below |
| `+` / `−` | left driver | right driver |

**The right amp's resistor depends on the board.** Adafruit's breakout (3006)
already has 1 MΩ from `SD` to `VIN`. Use **680 kΩ** there, in parallel with it,
for about 1.0 V. On boards without that pull-up, use **390 kΩ**. Measure `SD` to
GND with the amp powered: you want about 1.0 V. Then play something with a clear
left and right (on the Pi: `speaker-test -D default -c 2 -t wav`) and check that
each side comes from the right driver.

Never connect a speaker terminal to ground: the outputs are bridged.

## Microphones (2 × INMP441)

| Mic pin | Left mic | Right mic |
|---|---|---|
| `VDD` | 3.3 V | 3.3 V |
| `GND` | GND | GND |
| `SCK` | `MIC_BCLK` | `MIC_BCLK` |
| `WS` | `MIC_LRCLK` | `MIC_LRCLK` |
| `SD` | `MIC_DIN` | `MIC_DIN` (shared) |
| `L/R` | GND | 3.3 V |

Each mic drives `SD` only during its own half of the frame, so the two share one
wire. The Pi records both as one stereo stream and mixes them
(`audio.input.channel: mix`) or uses one. The ESP32-S3 listens with the left one.

## Display

**1.3" OLED (SH1106, I2C, default).** `VCC` to 3.3 V, `GND`, `SDA`, `SCL`. Its
address is usually 0x3C; on the Pi, check with `i2cdetect -y 1`. The 0.96" SSD1306
and 2.42" SSD1309 modules wire the same way (`display.oled.driver` on the Pi). The
2.42" boards often come set up for SPI and need resistors moved for I2C: see the
seller's notes.

**TM1637 4-digit display (Pi only).** `CLK` to GPIO23, `DIO` to GPIO24, `VCC` to
**3.3 V only**. These modules pull their data lines up to their own supply, and the
Pi's pins are not 5 V tolerant.

## Status LEDs (WS2812B)

`DIN` to `LED`, `5V` and `GND`, three LEDs from a 60 LED/m strip. Both brains send
a 3.3 V signal, which is below the WS2812B's specified input level at 5 V. Short
wires usually work anyway. If the colours flicker, feed the strip's 5 V through a
1N4001 diode (about 4.3 V), or add a 74AHCT125 level shifter.

## Power

```
USB-C breakout VBUS (5 V, 3 A supply)
 ├── the brain's 5V pin ..................... ESP32-S3 up to ~0.35 A, Pi up to ~0.5 A
 ├── left amp VIN ........................... up to ~0.7 A at full volume
 ├── right amp VIN .......................... up to ~0.7 A at full volume
 └── WS2812B strip .......................... up to 60 mA per LED at full white
the brain's 3.3 V pin ── mics, OLED ........ ~25 mA
```

Take each amp's power straight from the USB-C breakout, not through the brain, and
join all grounds at the breakout. Use 22 AWG for 5 V and ground to the amps;
26–28 AWG silicone wire is fine for signals.

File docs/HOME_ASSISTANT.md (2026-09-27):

# Home Assistant

- **ESP32-S3 brain:** [ESP32-S3 speaker](#esp32-s3-speaker), just below.
- **Raspberry Pi brain:** [Raspberry Pi speaker](#raspberry-pi-speaker).

The Assist pipeline, which picks the speech and language servers, is the same for
both: [2. An Assist pipeline on your own network](#2-an-assist-pipeline-on-your-own-network).

## ESP32-S3 speaker

The ESP32-S3 build is an ESPHome device, so Home Assistant sets it up like any
other.

1. Flash it: [esphome/README.md](../esphome/README.md#install).
2. Home Assistant discovers it. Add it under **Settings → Devices & services**,
   with the API encryption key from its YAML.
3. Create an Assist pipeline ([below](#2-an-assist-pipeline-on-your-own-network))
   and choose it on the speaker's device page.
4. For the temperature on the clock, set `temperature_entity` in its YAML
   ([settings](../esphome/README.md#settings)).
5. Expose the entities you want to control under **Settings → Voice assistants →
   Expose**.

Its media player takes announcements like any other:

```yaml
action: tts.speak
target:
  entity_id: tts.piper
data:
  media_player_entity_id: media_player.open_speaker   # your speaker's media player
  message: "The washing machine is done."
```

The alarm clock is on the device page (**Alarm**, **Alarm time**, **Alarm days**).
An automation can set it, or ring the speaker with the
`esphome.open_speaker_ring_alarm` action (named after the speaker's `name`).
Timers set by voice ring on the speaker.

The rest of this page is about the Raspberry Pi build.

## Raspberry Pi speaker

Open Speaker works with Home Assistant in two ways. Pick one with `pipeline.mode`
in `/etc/open-speaker/config.yaml`.

| | `homeassistant` (default) | `local` |
|---|---|---|
| Speech-to-text, language model, text-to-speech | An Assist pipeline in Home Assistant | Your own servers, called directly by the speaker ([LOCAL_AI.md](LOCAL_AI.md)) |
| Controlling devices | Home Assistant's agent (built in, or an LLM such as Ollama) | The `homeassistant` agent in the agent chain |
| Home Assistant needed | Yes | Optional |

In both modes the speaker handles timers, alarms, stop, snooze and volume itself,
so these keep working when Home Assistant or a server is down
(`pipeline.local_intents`).

The speaker uses Home Assistant's WebSocket and REST APIs with an access token.
You don't need a custom integration, and it doesn't appear as a device in Home
Assistant. Automations talk to it over its own small HTTP API (below).

## 1. Access token

1. In Home Assistant open your profile, then **Security**, then **Long-lived
   access tokens**, and create a token called `Open Speaker`.
2. On the speaker, put it in the secrets file:

   ```sh
   sudoedit /etc/open-speaker/secrets.env      # HA_TOKEN=eyJ...
   ```

3. Set the address in `/etc/open-speaker/config.yaml`:

   ```yaml
   homeassistant:
     url: http://homeassistant.local:8123
     token: ${HA_TOKEN}
   ```

4. Check it: `sudo open-speaker doctor` connects, authenticates and lists your
   Assist pipelines.

## 2. An Assist pipeline on your own network

Under **Settings → Voice assistants**, create a pipeline (or edit the default):

- **Speech-to-text**: Whisper or Speech-to-Phrase. Install the add-on, or run the
  server from [`server/docker-compose.yml`](../server/docker-compose.yml) and add
  it with **Settings → Devices & services → Add integration → Wyoming Protocol**
  (host of your server, port 10300).
- **Conversation agent**: *Home Assistant* for device control. Or add the
  **Ollama** integration (port 11434), allow it to control Home Assistant, and
  turn on *Prefer handling commands locally*. Common commands then skip the
  language model and stay fast.
- **Text-to-speech**: Piper (add-on, or Wyoming Protocol on port 10200).

The speaker uses your preferred pipeline. To use a different one, set its id:

```yaml
homeassistant:
  pipeline: 01jabcdefghijk      # "sudo open-speaker doctor" lists the ids
```

Expose the entities you want to control under **Settings → Voice assistants →
Expose**.

## 3. Temperature on the display

The display shows the time and a temperature, like the original. Use any
temperature sensor or weather entity:

```yaml
display:
  temperature:
    entity: weather.forecast_home        # or sensor.outdoor_temperature
```

## 4. Automations: announcements, timers, alarms

The speaker listens on port 10800. Set `api.token` (e.g. `${API_TOKEN}` from the
secrets file) if other people use your network, and send it as a bearer token.

| Method and path | Body | Does |
|---|---|---|
| `POST /api/say` | `{"text": "..."}` | Speaks the text, ducking any music |
| `POST /api/play` | `{"url": "http://..."}` | Plays a sound or media URL (MP3, WAV, ...) |
| `POST /api/listen` | | Starts listening, like the action button |
| `POST /api/stop` | | Stops speech, playback and ringing |
| `POST /api/volume` | `{"level": 40}` or `{"steps": -2}` | Sets the volume (0–100) |
| `POST /api/mute` | `{"microphone": true}`, `{"speaker": false}` | Mutes or unmutes |
| `GET /api/status` | | State, volume, mute, ringing, temperature, timers, alarms |
| `GET/POST/DELETE /api/timers` | `{"seconds": 300, "name": "tea"}` | Lists, starts or cancels (`?name=tea`) timers |
| `GET/POST/DELETE /api/alarms` | `{"time": "06:30", "repeat": "weekdays"}` | Lists, sets or cancels (`?time=06:30`) alarms |

`repeat` can be `daily`, `weekdays`, `weekends` or a list of days such as
`["mon", "wed", "fri"]`. Leave it out for a one-off alarm.

### Announcements

`configuration.yaml`:

```yaml
rest_command:
  speaker_say:
    url: http://open-speaker.local:10800/api/say
    method: POST
    headers:
      Authorization: !secret open_speaker_auth     # "Bearer <API_TOKEN>"
    content_type: application/json
    payload: '{"text": {{ message | tojson }}}'
  speaker_alarm:
    url: http://open-speaker.local:10800/api/alarms
    method: POST
    headers:
      Authorization: !secret open_speaker_auth
    content_type: application/json
    payload: '{"time": "{{ time }}", "repeat": "{{ repeat | default("") }}"}'
```

An automation:

```yaml
automation:
  - alias: Announce the washer
    triggers:
      - trigger: state
        entity_id: sensor.washer_status
        to: finished
    actions:
      - action: rest_command.speaker_say
        data:
          message: The washing is done.
```

### The speaker's state in Home Assistant

```yaml
rest:
  - resource: http://open-speaker.local:10800/api/status
    headers:
      Authorization: !secret open_speaker_auth
    scan_interval: 10
    sensor:
      - name: Speaker state
        value_template: "{{ value_json.state }}"
      - name: Speaker next alarm
        value_template: "{{ value_json.alarms | map(attribute='next') | sort | first | default('none') }}"
    binary_sensor:
      - name: Speaker ringing
        value_template: "{{ value_json.ringing | count > 0 }}"
```

With these you can, for example, turn the bedroom lights on slowly when the alarm
rings.

## 5. Music (optional)

The speaker doesn't include a music player. For Spotify Connect, install
[raspotify](https://github.com/dtcooper/raspotify) and set its output device to
`music` (`LIBRESPOT_DEVICE=music` in `/etc/raspotify/conf`). That device has its
own volume control, and the speaker turns it down while it talks:

```yaml
audio:
  output:
    duck_control: Music
```

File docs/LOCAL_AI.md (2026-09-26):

# Speech and AI models on your network

A Raspberry Pi Zero 2 W has four small Cortex-A53 cores and 512 MB of RAM. That is
plenty for a speaker, but not for speech recognition: even Whisper's smallest
model would take several seconds per command. So the work is split:

| On the speaker | On another machine on your network |
|---|---|
| Wake word (microWakeWord, a few percent of one core) | Speech-to-text |
| Recording, end-of-speech detection, playback | The conversation agent / language model |
| Timers, alarms, volume, stop, snooze | Text-to-speech |
| Display, LEDs, buttons | |

The "other machine" can be whatever already runs all the time: the Home
Assistant box, a mini PC, a NAS with Docker, or a desktop with a GPU.
[`server/docker-compose.yml`](../server/docker-compose.yml) starts everything
below with one command.

## Choosing models

**Speech-to-text**

| Server | Good for |
|---|---|
| [Speech-to-Phrase](https://github.com/OHF-Voice/speech-to-phrase) (Home Assistant add-on) | The lightest option; fast even on a Raspberry Pi 4. It only understands commands built from your Home Assistant devices and areas, so no open questions. |
| [faster-whisper](https://github.com/rhasspy/wyoming-faster-whisper) `tiny-int8` / `base-int8` | Any sentence, on a CPU. `base-int8` is the compose file's default. |
| faster-whisper `small-int8` or larger | Better accuracy; wants a fast CPU or a GPU |
| Any OpenAI-compatible `/v1/audio/transcriptions` server ([speaches](https://github.com/speaches-ai/speaches), LocalAI, vLLM) | If you already run one |

**Conversation agent / language model**

- Home Assistant's built-in agent: device control only, instant.
- [Ollama](https://ollama.com) with a small model that supports tool calling, such
  as `llama3.2` (3B) or `qwen2.5:7b`. On a CPU, expect a few seconds per answer;
  a GPU makes it feel instant.
- Anything with an OpenAI-compatible `/v1/chat/completions` API: llama.cpp's
  `llama-server`, vLLM, LocalAI, LM Studio.

**Text-to-speech**

- [Piper](https://github.com/rhasspy/wyoming-piper): fast on a CPU, many voices.
- Any OpenAI-compatible `/v1/audio/speech` server, e.g. Kokoro through speaches
  or Kokoro-FastAPI: more natural, heavier.

## Option A: through Home Assistant (default)

Add the servers to Home Assistant and build an Assist pipeline from them; see
[HOME_ASSISTANT.md](HOME_ASSISTANT.md#2-an-assist-pipeline-on-your-own-network).
The speaker needs only:

```yaml
pipeline:
  mode: homeassistant
homeassistant:
  url: http://homeassistant.local:8123
  token: ${HA_TOKEN}
```

## Option B: the speaker calls the servers itself

Useful without Home Assistant, or to mix engines Home Assistant doesn't offer. The
agents are tried in order: here Home Assistant controls the devices, and anything
it doesn't understand goes to the language model.

```yaml
pipeline:
  mode: local

stt:
  engine: wyoming
  uri: tcp://192.168.1.10:10300          # faster-whisper or Speech-to-Phrase

agents:
  - engine: homeassistant                # optional; needs the homeassistant section
  - engine: openai
    url: http://192.168.1.10:11434/v1    # Ollama
    model: llama3.2

tts:
  engine: wyoming
  uri: tcp://192.168.1.10:10200          # Piper
  voice: en_US-lessac-medium

vad:
  engine: energy        # detects the end of your sentence; microvad is more robust
  silence_seconds: 0.8
```

OpenAI-compatible servers instead of Wyoming:

```yaml
stt:
  engine: openai
  url: http://192.168.1.10:8000/v1
  model: Systran/faster-distil-whisper-small.en
tts:
  engine: openai
  url: http://192.168.1.10:8000/v1
  model: speaches-ai/Kokoro-82M-v1.0-ONNX
  voice: af_heart
```

Set `api_key:` on any of them if your server wants one (e.g. `${OPENAI_API_KEY}`
from `/etc/open-speaker/secrets.env`).

## Wake word

microWakeWord runs on the speaker by default (`okay_nabu`, `hey_jarvis`,
`hey_mycroft`, `alexa`, or your own model file). openWakeWord also runs on the
speaker but needs several times the CPU. Or run it on the server:

```yaml
wake:
  engine: wyoming
  uri: tcp://192.168.1.10:10400      # docker compose --profile wakeword up -d
  names: [ok_nabu]
```

This streams the microphone to the server all the time, so the on-device default
is usually better.

## Making it quick

- The installer turns off Wi-Fi power saving. It adds noticeable delay to every
  request.
- With Wyoming, your voice streams to the server while you talk; OpenAI-style
  servers receive it in one piece after you stop.
- Keep models loaded: Ollama unloads a model after 5 minutes by default
  (`OLLAMA_KEEP_ALIVE=24h` keeps it in memory).
- Timers, alarms, stop and volume never leave the speaker, so they answer at once.

Check everything with `sudo open-speaker doctor`: it tries each configured server
and reports what works.

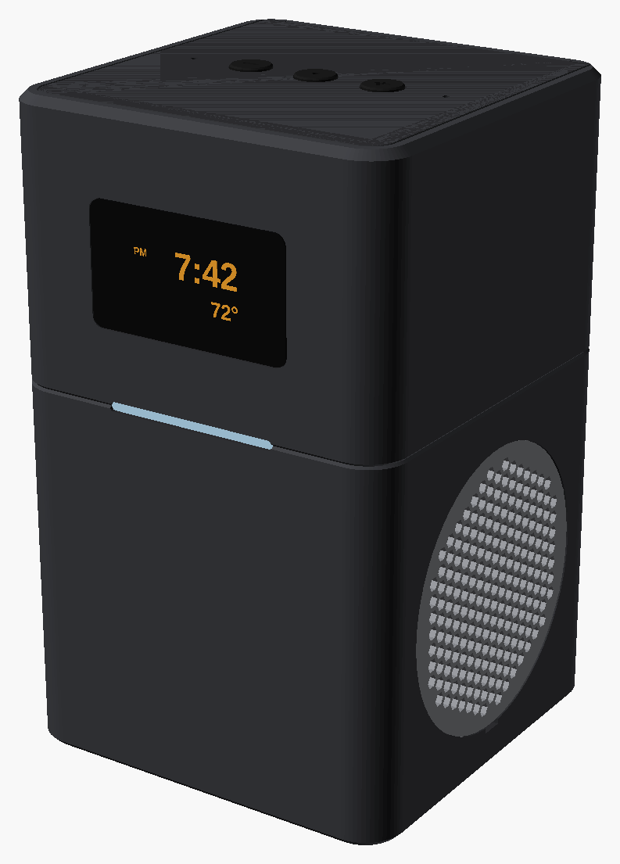
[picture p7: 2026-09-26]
docs/images/enclosure-front-dark.png

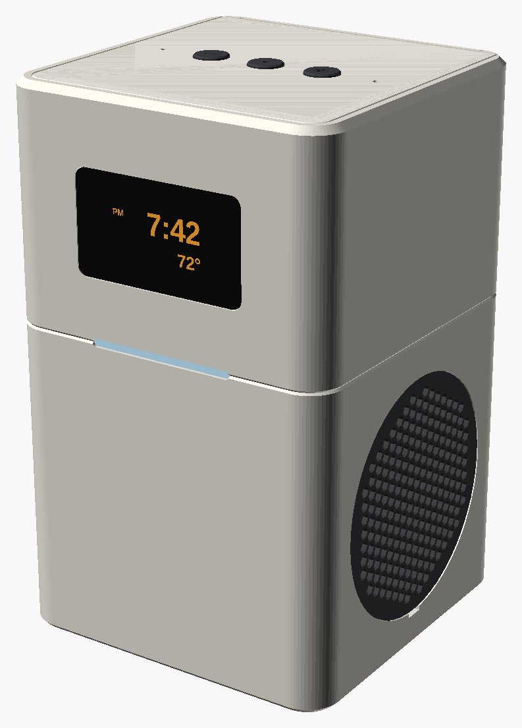
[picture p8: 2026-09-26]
docs/images/enclosure-front.png

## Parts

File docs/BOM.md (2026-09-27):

# Bill of materials

Everything except the two drivers is bought new. Prices are in US dollars, checked
on 26 September 2026, without tax or shipping. A plain price is the store's listed
price that day. **≈** marks an estimate where the listed price couldn't be
confirmed: check it in the store.

To shop, open [`shopping-list.html`](shopping-list.html) from your copy of the
repository in a browser. It has every part with its store link and searches at
other stores to compare prices. It also works out what to buy for any number of
speakers and lets you tick parts off as you buy them.

The speaker has one of two brains, an ESP32-S3 or a Raspberry Pi Zero 2 W
([which one?](../README.md#two-brains)). Everything else is the same for both.

| | Per speaker | First build |
|---|--:|--:|
| [Brain: ESP32-S3](#esp32-s3) | $15.00 | $15.00 |
| [Brain: Raspberry Pi Zero 2 W](#raspberry-pi-zero-2-w) | ≈ $27.00 | ≈ $27.00 |
| [Electronics](#electronics) | ≈ $42.64 | ≈ $112.57 |
| [Enclosure hardware](#enclosure-hardware) | ≈ $3.99 | ≈ $58.86 |
| [Filament](#filament) | $13.10 | $28.79 |
| **Speaker with the ESP32-S3** | **≈ $75** | **≈ $215** |
| **Speaker with the Pi** | **≈ $87** | **≈ $227** |
| [Desk test parts](#desk-test) (reusable) | | ≈ $12.90 |
| [Shop supplies](#shop-supplies) | | ≈ $21.00 |

*Per speaker* counts only what one speaker uses. *First build* is what you pay,
because screws, wire, filament and several modules only come in packs. Of the
$215 for the ESP32-S3 build, $136 is estimated, mostly Amazon packs. A second
speaker costs about $53 more with the ESP32-S3, or $65 with the Pi: the brain,
amplifiers, USB-C breakout, power supply and switches, plus another pack of
microphones (and a microSD card for the Pi).

## Brain

### ESP32-S3

| Part | Qty | Buy | Price | Per speaker |
|---|:-:|---|--:|--:|
| ESP32-S3-DevKitC-1-N8R8: 8 MB flash, 8 MB PSRAM, pins soldered on | 1 | [DigiKey](https://www.digikey.com/en/products/detail/espressif-systems/ESP32-S3-DEVKITC-1-N8R8/15295894) | $15.00 | $15.00 |

It runs ESPHome ([esphome/](../esphome)) and sits on a printed cradle; the harness
plugs onto its pins. It needs the 8 MB of PSRAM for the wake word, so avoid the
plain N8 version.

### Raspberry Pi Zero 2 W

| Part | Qty | Buy | Price | Per speaker |
|---|:-:|---|--:|--:|
| Raspberry Pi Zero 2 WH (SC0721, header soldered on) | 1 | [DigiKey](https://www.digikey.com/en/products/detail/raspberry-pi/SC0721/24627135) | $18.00 | $18.00 |
| microSD card: SanDisk Ultra 32 GB A1 (SDSQUA4-032G-GN6MA) | 1 | [Amazon](https://www.amazon.com/dp/B08GY9NYRM) | ≈ $9 | ≈ $9.00 |

It runs the Linux firmware ([firmware/](../firmware)). The Pi is also at
[PiShop](https://www.pishop.us/product/raspberry-pi-zero-2w-with-headers/) and
[Adafruit](https://www.adafruit.com/product/6008) ($19.80), but was out of stock at
most stores on 26 September. The Zero 2 W without the header is $15, but then you
solder the header yourself.

## Electronics

| Part | Qty | Buy | Price | Per speaker |
|---|:-:|---|--:|--:|
| Adafruit MAX98357A I2S amplifier (3006) | 2 | [Adafruit](https://www.adafruit.com/product/3006) | $5.95 each | $11.90 |
| INMP441 I2S microphone module: AITRIP, pack of 3 | 2 | [Amazon](https://www.amazon.com/dp/B0972XP1YS) | ≈ $14 | ≈ $9.33 |
| Adafruit USB-C breakout (4090) | 1 | [Adafruit](https://www.adafruit.com/product/4090) | $2.95 | $2.95 |
| Raspberry Pi 15 W USB-C power supply, US plug, black | 1 | [PiShop](https://www.pishop.us/product/raspberry-pi-15w-power-supply-us-black/) | ≈ $8 | ≈ $8.00 |
| 1.3" OLED, 128 × 64, SH1106, I2C, white: Hosyond, pack of 5 | 1 | [Amazon](https://www.amazon.com/dp/B0C3L7N917) | ≈ $20 | ≈ $4.00 |
| WS2812B strip, 60 LED/m, IP30, black PCB, 1 m: BTF-LIGHTING | 3 LEDs | [Amazon](https://www.amazon.com/dp/B01CDTED80) | ≈ $14 | ≈ $0.70 |
| Omron B3F-1000 tactile switch, 6 × 6 × 4.3 mm | 4 | [DigiKey](https://www.digikey.com/en/products/detail/omron-electronics-inc-emc-div/B3F-1000/33150) | $0.35 each | $1.40 |
| 680 kΩ resistor, ¼ W (Stackpole CFM14JT680K) | 1 | [DigiKey](https://www.digikey.com/en/products/detail/stackpole-electronics-inc/CFM14JT680K/1742269) | ≈ $0.10 | ≈ $0.10 |
| 1N4001G diode (onsemi) | 1 | [DigiKey](https://www.digikey.com/en/products/detail/onsemi/1N4001G/1485468) | $0.27 | $0.27 |
| Perfboard: ELEGOO kit of 32 double-sided boards | 2 boards | [Amazon](https://www.amazon.com/dp/B072Z7Y19F) | ≈ $12 | ≈ $0.75 |
| Jumper wires, female/female, 40 × 150 mm (Adafruit 266) | ~10 | [Adafruit](https://www.adafruit.com/product/266) | $3.95 | $0.99 |
| Silicone wire, 26 AWG, 6 colours | ~4 m | [Amazon](https://www.amazon.com/dp/B07G2LRX68) | ≈ $13 | ≈ $1.50 |
| Silicone wire, 22 AWG, red and black | ~1.5 m | [Amazon](https://www.amazon.com/dp/B07ZFP8KCN) | ≈ $11 | ≈ $0.75 |

- **Microphones.** The same AITRIP pack of 3 was $14.43 on
  [eBay](https://www.ebay.com/itm/235775726409).
- **Power supply.** The same supply is [Adafruit 4298](https://www.adafruit.com/product/4298),
  $8.74, but it was out of stock on 26 September. Any 5 V 3 A USB-C supply works.
- **OLED.** The enclosure is drawn for this module: a 35.4 × 33.5 mm board with a
  29.42 × 14.70 mm active area. Other 1.3" SH1106 I2C modules are usually the same
  size, but check before you buy one.
- **Switches.** The top plate and back panel are drawn for 4.3 mm switches. For a
  different switch, set `switch_height` in the model to its height from the board
  to the top of the plunger.
- **Resistor.** 680 kΩ is for the Adafruit amplifier, which already has a 1 MΩ
  pull-up. Other MAX98357A boards need
  [390 kΩ](https://www.digikey.com/en/products/detail/stackpole-electronics-inc/CF14JT390K/1741414)
  instead ([why](../hardware/schematics/gpio_pinout.md#amplifiers-2--max98357a)).
- **Diode.** Only needed if the LEDs flicker
  ([wiring](../hardware/schematics/gpio_pinout.md#status-leds-ws2812b)), but at
  $0.27 it is cheaper than a second order.
- **Perfboard.** The three top switches go on a 50 × 12 mm strip cut from one of
  the 2 × 8 cm boards, the mute switch on a 24 × 14 mm piece.
- **Jumper wires.** Cut in half, they give the harness female housings for the
  Pi's header, so the top plate and back panel stay removable.

## Enclosure hardware

| Part | Qty | Buy | Price | Per speaker |
|---|:-:|---|--:|--:|
| Heat-set inserts, M3 × 5.7 mm: ruthex, pack of 100 | 6 | [Amazon](https://www.amazon.com/dp/B08BCRZZS3) | $9.49 | $0.57 |
| Countersunk hex socket screws, M3 × 8, 10 and 12 mm, 100 each: uxcell | 14 × M3 × 8, 4 × M3 × 10 | [Amazon](https://www.amazon.com/dp/B0C6LQ3B5W) | ≈ $11 | ≈ $0.66 |
| Self-tapping pan head screws, M2 and M2.6: kit of 400 | 4 × M2 × 6, 4 × M2.6 × 6 | [Amazon](https://www.amazon.com/dp/B07VQZXGH2) | ≈ $9 | ≈ $0.18 |
| Rubber feet: 3M Bumpon SJ5312, 12.7 × 3.6 mm, pack of 56 | 4 | [Amazon](https://www.amazon.com/dp/B000NG60SW) | ≈ $10 | ≈ $0.71 |
| Closed-cell EVA foam tape, single-sided, 1 mm × 5 mm × 5 m | ~1 m | [Amazon](https://www.amazon.com/dp/B0FMF21TZD) | ≈ $7 | ≈ $1.40 |
| Smoked acrylic sheet, 1/16" (1.5 mm), 12 × 12", #2074 | one 51.5 × 29.5 mm window | [eBay](https://www.ebay.com/itm/222235546514) | ≈ $7 | ≈ $0.25 |
| Polyester fibre fill: Poly-Fil, 12 oz | a handful | [Walmart](https://www.walmart.com/ip/26678911) | $5.37 | $0.22 |

- **Inserts.** They go into 4.0 mm holes, the size in the model (`insert_diameter`).
- **M2.6 screws** hold the Pi, or the ESP32-S3's cradle, on the deck's standoffs;
  M2.5 × 6 machine screws work too. The M2 screws hold the two switch boards.
- **Feet.** The recesses underneath are 13.2 mm across, for these 12.7 mm feet.
- **Foam tape.** The seal gaps in the model are drawn for 1 mm foam; thicker tape
  won't compress enough. [uxcell 1 mm × 10 mm](https://www.amazon.com/dp/B01L6TE0UO)
  works too if you cut it narrower.
- **Acrylic.** #2074 is the darker smoke and hides the display best when it is off;
  #2064 is lighter. Measure your sheet and set `window_thickness` in the model to
  its thickness (1.6 mm by default) so the window sits flush. One sheet makes about
  50 windows. [Canal Plastics](https://www.canalplastic.com/products/2064-gray-smoke-acrylic-sheet)
  and [T&T Plastic Land](https://www.ttplasticland.com/products/custom-gray-smoke-transparent-2064-acrylic-sheet)
  cut acrylic to size.

## Filament

| Part | Qty | Buy | Price | Per speaker |
|---|:-:|---|--:|--:|
| PETG, 1.75 mm, 1 kg: Prusament Signal White | ~455 g | [Printed Solid](https://www.printedsolid.com/products/prusament-petg-1-75mm-1kg-signal-white) | $28.79 | $13.10 |

About 450 g for the printed parts (10 g more for the ESP32-S3's cradle) and 5 g
for the light diffuser. The diffuser has
to be white or natural PETG, so a white spool covers everything. For a dark
speaker, print the rest in
[Prusament Jet Black](https://www.printedsolid.com/products/prusament-petg-1-75mm-1kg-jet-black),
also $28.79, and the diffuser in white. Both are sale prices; Signal White is
normally $35.99. Any PETG works.

## Desk test

Reusable parts for testing everything on the desk before it goes into the
enclosure ([build guide, step 4](ASSEMBLY_GUIDE.md#4-test-on-the-desk)).

| Part | Qty | Buy | Price |
|---|:-:|---|--:|
| Half-size breadboard, 400 points (Adafruit 64) | 1 | [Adafruit](https://www.adafruit.com/product/64) | ≈ $5.00 |
| Jumper wires, female/male, 40 × 150 mm (Adafruit 826) | 1 pack | [Adafruit](https://www.adafruit.com/product/826) | $3.95 |
| Jumper wires, male/male, 40 × 150 mm (Adafruit 758) | 1 pack | [Adafruit](https://www.adafruit.com/product/758) | ≈ $3.95 |

## Shop supplies

| Part | Use | Buy | Price |
|---|---|---|--:|
| E6000 clear adhesive, 3.7 oz | Holds the display window | [Amazon](https://www.amazon.com/dp/B007TSYNG8) | ≈ $6 |
| Heat-shrink tubing kit, 3:1, adhesive-lined: Wirefy, 200 pieces | Wire splices | [Amazon](https://www.amazon.com/dp/B089D82FLG) | ≈ $15 |

## Where to order

For the ESP32-S3 build, with the desk test parts and shop supplies:

| Store | Parts | First build |
|---|---|--:|
| Amazon | Microphones, OLED, LED strip, perfboard, wire, fasteners, feet, foam tape, shop supplies | ≈ $151.49 |
| Adafruit | Amplifiers, USB-C breakout, jumper wires, breadboard | ≈ $31.70 |
| Printed Solid | Filament | $28.79 |
| DigiKey | ESP32-S3, switches, resistor, diode | ≈ $16.77 |
| PiShop | Power supply | ≈ $8.00 |
| eBay | Acrylic | ≈ $7.00 |
| Walmart | Fibre fill | $5.37 |

For the Pi build, DigiKey has the Pi instead ($18.00) and Amazon the microSD card
as well (≈ $9).

Shipping from seven stores adds up. DigiKey resells most Adafruit products and
PiShop has the Pi too, so check whether you can combine orders.

## From the original speaker

| Part | Qty | Notes |
|---|:-:|---|
| Full-range drivers, ~52 mm, 4 Ω | 2 | Measure them first: [measurements.md](../hardware/speaker_specs/measurements.md) |
| Passive radiator | 0–1 | Only for `bass_mode = "passive_radiator"` |

## Tools

Soldering iron (it also sets the heat-set inserts) and solder, multimeter, wire
strippers, flush cutters, a small Phillips screwdriver, a 2 mm hex key for the M3
screws, a hot glue gun, a craft knife and steel ruler to score the acrylic, a fine
file, and a 3D printer with at least 160 mm of Z height.

## Servers

You also need an always-on machine on your network for speech recognition and the
language model. Home Assistant's own box is enough for Speech-to-Phrase and Piper.
See [LOCAL_AI.md](LOCAL_AI.md).

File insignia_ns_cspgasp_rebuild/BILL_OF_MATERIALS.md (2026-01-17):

# Bill of Materials: Insignia NS-CSPGASP Rebuild

**Objective:** Hardware shopping list for upgrading the Insignia Smart Speaker with a Raspberry Pi Zero 2 W.
**Status:** VALIDATED (All pinouts and dimensions confirmed).

## 1. Core Electronics (The "Brains")

| Component | qty | Specifications | Recommended SKUs | Est. Cost |
| :--- | :-: | :--- | :--- | :--- |
| **Controller** | 1 | **Raspberry Pi Zero 2 W**<br>*(Must be the "2 W" for quad-core power)* | • [Adafruit 5291](https://www.adafruit.com/product/5291)<br>• [The Pi Hut](https://thepihut.com/products/raspberry-pi-zero-2-w) | $15.00 |
| **Storage** | 1 | **MicroSD Card (16GB - 32GB)**<br>*(Class 10 / A1 rated)* | • SanDisk Ultra<br>• Samsung EVO Select | $6.00 |

## 2. Interface Hardware (The "Custom HAT")

| Component | qty | Specifications | Recommended SKUs | Est. Cost |
| :--- | :-: | :--- | :--- | :--- |
| **Proto HAT** | 1 | **Raspberry Pi Zero Proto HAT** (Shim)<br>*(Blank PCB to mount the breakout)* | • **Adafruit 3203** (Perma-Proto)<br>• **Pimoroni** Zero LiPo Shim (generic)<br>• [DigiKey/Mouser Alt] | $5.00 |
| **FPC Breakout** | 1 | **20-Pin 0.5mm** to DIP Adapter<br>*(Input: Mics + Touch + LED Pass-through)*<br>*(MUST have ZIF connector)* | • **Crystalfontz:** CFABB-CS050Z20G-A0<br>• **7Semi:** 20 Pin 0.5mm FFC Breakout<br>• **Tinkersphere:** 20 Pin 0.5mm FPC to DIP | $8-12 |
| **Extensions** | 1 | **FPC Extension Kit** (or Long Cables)<br>*(Essential for debugging)* | • **20-Pin 0.5mm Cable** (Main Link)<br>• **10-Pin 1.0mm Cable** (Inter-board Link) | $10.00 |
| **Audio Amp** | **2** | **MAX98357A** I2S Mono Amp<br>*(Buy TWO for Stereo - Confirmed Twin Amp topology)* | • **Adafruit 3006**<br>• **Amazon:** *"MAX98357A Breakout"* (Pack of 2) | $12.00 |
| **GPIO Header** | 1 | **2x20 Right-Angle Logic Header** (Male)<br>*(Required for 8mm Depth Limit)* | • **Adafruit:** 2x20 Right Angle Male Header<br>• **BC Robotics:** ACC-070<br>• **Amazon:** "2x20 Right Angle Header Male" | $2.00 |
| **Power Module** | 1 | **12V to 5V (3A) Buck Converter**<br>*(Essential if original brick is 12V)* | • **Pololu:** D24V50F5 (5V 5A)<br>• **Amazon:** "MP1584 Buck Converter"<br>• **Generic:** LM2596 Module (Bulky but works) | $3-5 |
| **Resistor** | 1 | **330kΩ - 470kΩ Resistor**<br>*(Required to set "Right Channel" on Amp 2)* | Any standard through-hole resistor. | $0.10 |

## 3. Wiring & Consumables

| Component | Description | Usage |
| :--- | :--- | :--- |
| **Ribbon Cable** | **20-Pin 0.5mm FFC** (Type A or B) | Keep the original! But buy a spare just in case ($2). |
| **Wire** | 24-26 AWG Silicone Wire | For wiring the HAT to the Pi GPIO. |
| **Power Cable** | **JST-PH 2-Pin** Pigtail (Female) | To splice into the internal speaker wire (optional but clean). |
| **Mounting** | Double-sided Foam Tape | To stick the Breakout Board to the Proto HAT. |

## 4. Tools Required
-   [ ] Soldering Iron & Solder
-   [ ] Flux (makes the job 10x easier)
-   [ ] Multimeter (for verifying the VCC voltage before first boot)
-   [ ] Wire Strippers

## Total Project Cost Estimate
**~ $45 - $55 USD** (Assuming you own the tools)

> [!TIP]
> **Don't Forget Headers!**
> If your Pi Zero 2 W *doesn't* come with pre-soldered GPIO headers, make sure to buy a **2x20 Male Header** strip (2.54mm) and solder it on!

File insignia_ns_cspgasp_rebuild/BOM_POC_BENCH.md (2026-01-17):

# PoC Test Bench: "Safe Sniffing" Setup

**Objective:** Safely characterize the signal pinout between the Main Board and Top Board without destroying the unit.

## 1. Required Components (The "Spread Out" Kit)
To access the signals while powered, you must extend the connection between the cemented Top Board and the Main Board.

| Component | Qty | Critical Spec | Search / SKU Examples | Why? |
| :--- | :--- | :--- | :--- | :--- |
| **FPC Extension Cable** | 1 | **20-Pin, 0.5mm Pitch** (Type A: Same Side) | • **Electrokit:** 41022543 (Type A)<br>• **Partsbaba:** PBFFC0344 (Type A)<br>• **Amazon:** "FFC Cable Type A Same Side" | **Crucial:** Type B (Reverse) will flip pin 1 to pin 20 and fry your board. Get Type A. |
| **FPC Coupler / Extender** | 1 | **20-Pin, 0.5mm Pitch** (Slide-Lock ZIF) | • **Adafruit:** 5203<br>• **DigiKey:** 1528-5203-ND<br>• **Sunrom:** 7631 | Joins the original short ribbon to your extension. |
| **Extension Jumper (Optional)** | 1 | **10-Pin, 1.0mm Pitch** | • **Amazon:** "10 pin 1.0mm FFC Cable" | For the LED Display if you want that active too. |
| **Logic Analyzer** | 1 | 8-Channel 24MHz | • **Amazon:** "HiLetgo 24MHz 8CH"<br>• **SparkFun:** TOL-18627 | **Essential** for decoding I2C data (display protocol). |

## 2. Bench Layout Map
This layout allows you to use the **Original Power Supply** while keeping the pin-dense ribbon cable exposed flat on your desk for probing.

```text
[ WALL ]
   ║
   (DC Jack)
   ║
[ CONDOR MAIN BOARD ]
   ║
   ║ (FPC Cable 1)
   ▼
[ BREAKOUT BOARD A ]  <-- (Input Side)
   ║
   ║  <-- JUMPER WIRES (The "Bridge") -->
   ║  * PROBE HERE! Attach clips to these wires.
   ║  * Signals flow through wires from Main to Top.
   ║
[ BREAKOUT BOARD B ]  <-- (Output Side)
   ║
   ║ (FPC Cable 2)
   ▼
[ CONDOR TOP BOARD ]
```

### 2.1 How the "Bridge" Works
1.  **Connection:** The signals flow from the **Main Board** -> **Cable 1** -> **Breakout A** -> **Jumper Wires** -> **Breakout B** -> **Cable 2** -> **Top Board**. The device acts exactly as if it were connected by a single cable.
2.  **Safety:** Instead of probing 0.5mm pads, you attach your probes to the **Jumper Wires** connecting the two boards.
    *   **Spacing:** Wires are spread out (2.54mm or more).
    *   **Grip:** Logic Analyzer hooks grab the wire insulation/metal securely.
    *   **No Shorts:** You can move wires apart to ensure they never touch.
3.  **Control:** You can unplug *one single wire* (e.g., disconnected the 3.3V line) to see what happens, without cutting any ribbon cables.

### 2.2 Safety Protocol: Preventing the Magic Smoke
**You are right to be paranoid. Wiring 20 jumpers creates 20 chances to swap a pin.**
Follow this procedure BEFORE plugging in the power brick:

1.  **Wire Methodically:** Connect Pin 1 to Pin 1. Pin 2 to Pin 2. Do not cross connect anything yet.
2.  **The "Beep" Test (Crucial):**
    *   Set Multimeter to *Continuity Mode* (Beep).
    *   Touch one probe to **Pin 1 Solder Pad** on Breakout A.
    *   Touch other probe to **Pin 1 Solder Pad** on Breakout B.
    *   **It MUST Beep.** (Continuity Confirmed).
    *   Repeat for Pin 20.
3.  **The "Short" Test:**
    *   Check continuity between **Pin 1** and **Pin 2**.
    *   **It MUST NOT Beep.** (No Shorts).
    *   Check continuity between **GND** (likely large planes) and **VCC** (if known).
4.  **Only then, Plug it in.**

### 2.3 Connecting the Logic Analyzer
The beauty of the Breadboard Bridge is that **rows are shared**.
1.  **GND First:** Connect the Logic Analyzer's `GND` wire to any wire you confirmed is Ground (Bridge Pin X).
2.  **Tap the Signal:**
    *   **Hole A:** Wire from Breakout 1 (Signal IN).
    *   **Hole B:** Wire to Breakout 2 (Signal OUT).
    *   **Hole C:** **Plug in your Logic Analyzer Channel 1 wire here.**
3.  Now the Analyzer "sees" the same voltage as the wire, without interrupting it.
4.  Repeat for Channels 2-8 to sniff multiple pins at once.

## 3. Diagnostic Tools
| Item | Spec | Search / SKU Examples | Why? |
| :--- | :--- | :--- | :--- |
| **Multimeter** | Voltmeter/Connectivity | Any Reliable Brand | Identifying 5V, 3.3V, and GND rails. |
| **Precision Needle Probes** | **< 1mm Tip** (Gold Plated) | • **Uxcell:** P50B (0.5mm Spear Tip)<br>• **Pace:** 1121-0680-P5<br>• **Amazon:** "0.5mm Multimeter Probe Spec" | **Essential.** Standard probes are too fat for 0.5mm pitch and will cause shorts. |
| **Logic Analyzer** | 24MHz 8-channel | **HiLetgo** / **KeeYees** (Generic 24MHz) | **HIGHLY RECOMMENDED.** Essential for decoding Display I2C. |

## 4. Workflows
1.  **Voltage Check:** Probe the generic pads on the Main Board first to confirm the 5V/12V rails.
2.  **Pinout Sniffing:**
    -   Connect Logic Analyzer connecting ground to a chassis shield.
    -   Tap channels 0-7 onto the FPC Extension wires.
    -   Capture signal traces during boot-up to identify `SDA`, `SCL`, `I2S` clocks.

## 5. Shopping List
Use this checklist to track your orders.

### Phase 1: Bench Essentials (For Sniffing)
*These items are required to probe the original board safely.*
- [x] **FPC Breakout Boards (The "Bridge")**
    - [x] [Amazon Search: "20 pin 0.5mm to DIP Adapter with Connector"](https://www.amazon.com/s?k=20+pin+0.5mm+to+dip+adapter+pcb+converter) - **BUY TWO (2)**.
    - **CRITICAL:** Ensure the board has the **FPC Connector PRE-SOLDERED**.
- [x] **FPC Extension Cables (20-pin 0.5mm)**
    - [x] [Adafruit #5203 (Coupler/Extender)](https://www.adafruit.com/product/5203) - *Buy 2*
    - [x] [Amazon Search: "20 pin 0.5mm ffc cable 200mm"](https://www.amazon.com/s?k=20+pin+0.5mm+ffc+cable+200mm) - *Get a multipack*
- [x] **Digital Multimeter (Fast Continuity)**
    - [x] [ANENG SZ06 (User Selected)](https://a.co/d/4sI5lbR) - *Confirmed: Has Audible Buzzer.*
- [x] **Logic Analyzer**
    - [x] [HiLetgo USB Logic Analyzer (Amazon)](https://www.amazon.com/dp/B077LSG5P2) - *Standard Clone*
- [x] **Extension Jumper (10-pin 1.0mm)**
    - [x] [Amazon Search: "10 pin 1.0mm pitch ffc cable"](https://www.amazon.com/s?k=10+pin+1.0mm+pitch+ffc+cable) - *Optional: For LED Display*

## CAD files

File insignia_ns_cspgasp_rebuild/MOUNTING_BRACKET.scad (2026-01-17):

// Insignia NS-CSPGASP "Landscape" Bracket
// CORRECTION: LANDSCAPE ORIENTATION (Horizontal).
// FIT: Pi (65mm) fits across Chassis (66mm).
// LAYOUT:
// - Bottom: Pi Zero 2 W (Horizontal). GPIO Header facing UP.
// - Top: HAT Breakout (Horizontal).
// - Top Rear: DAC Backpack.

$fn = 60;

// --- DIMS ---
chassis_w = 66; 
chassis_h = 80;
screw_dia = 3.4;

// Component Mounting Patterns
// PI ZERO (Landscape)
// Holes are 58mm apart horizontally, 23mm vertically.
pi_mount_w = 58; 
pi_mount_h = 23;

module suspension_frame() {
    union() {
        // 1. OUTER FRAME
        difference() {
            hull() {
                for(x=[-1,1]) for(y=[-1,1])
                    translate([x*chassis_w/2, y*chassis_h/2, 0]) cylinder(h=2, r=5, center=true);
            }
            // Cutout
            rounded_rect([chassis_w-12, chassis_h-12, 10], 2);
            // Chassis Holes
            for(x=[-1,1]) for(y=[-1,1])
                translate([x*chassis_w/2, y*chassis_h/2, 0]) cylinder(h=10, r=screw_dia/2, center=true);
        }
        
        // 2. PI MOUNTING BARS (Bottom Zone - Landscape)
        // Spans left-to-right to grab the wide mounting holes (58mm)
        translate([0, -20, 0]) { // Shifted Down
             difference() {
                 union() {
                     // Top Bar of Pi Mount
                     translate([0, pi_mount_h/2, 0]) cube([64, 5, 2], center=true);
                     // Bottom Bar of Pi Mount
                     translate([0, -pi_mount_h/2, 0]) cube([64, 5, 2], center=true);
                     // Vertical Links (Sides)
                     translate([-30, 0, 0]) cube([4, 25, 2], center=true);
                     translate([30, 0, 0]) cube([4, 25, 2], center=true);
                 }
                 // Mounting Holes
                 for(x=[-1,1]) for(y=[-1,1])
                    translate([x*pi_mount_w/2, y*pi_mount_h/2, 0]) cylinder(h=10, r=1.25, center=true);
             }
        }
        
        // 3. HAT MOUNTING (Top Zone)
        translate([0, 25, 0]) {
             difference() {
                 // Cross Bar
                 cube([40, 6, 2], center=true);
                 // Holes (20mm spacing)
                 translate([-10, 0, 0]) cylinder(h=10, r=1, center=true);
                 translate([10, 0, 0]) cylinder(h=10, r=1, center=true);
             }
        }
        
        // 4. DAC CAGE (Rear Top Zone)
        translate([0, 25, -4]) { 
             difference() {
                 cube([45, 18, 6], center=true);
                 cube([41, 14, 10], center=true);
             }
             // Studs
             translate([-12, 0, 0]) cylinder(h=4, r=2, center=true);
             translate([12, 0, 0]) cylinder(h=4, r=2, center=true);
        }
    }
}

module visualize_landscape() {
    // Pi Zero (Green) - Horizontal
    // GPIO Header should be at the TOP alignment.
    translate([0, -20, 1.6]) {
        color("green") cube([65, 30, 1.6], center=true); // PCB
        
        // GPIO Header (Black) - RIGHT ANGLE (Low Profile)
        // Sits flat against PCB. Height ~2.5mm. Pin direction: UP (Towards HAT).
        translate([0, 12, 1.6/2 + 1.25]) color("black") cube([50, 5, 2.5], center=true);
        // The Pins sticking OUT (Gold)
        translate([0, 15, 1.6/2 + 1.25]) color("gold") cube([50, 6, 0.6], center=true);
        // Wire Path Visualizer (Grey)
        %translate([0, 20, 2]) color("grey", 0.5) cube([40, 10, 2], center=true); 
        
        // USB Ports (Silver) - Bottom Edge
        translate([-6, -15, 2]) color("silver") cube([8, 6, 3], center=true);
        translate([6, -15, 2]) color("silver") cube([8, 6, 3], center=true);
    }
    
    // HAT (Purple)
    translate([0, 25, 2]) color("purple") cube([26, 20, 1.6], center=true); 
    
    // DACs (Blue)
    translate([-12, 25, -4]) color("blue") cube([15, 18, 5], center=true);
    translate([12, 25, -4]) color("blue") cube([15, 18, 5], center=true);
}

// Utility
module rounded_rect(size, radius) {
    x = size[0]; y = size[1]; z = size[2];
    cube(size, center=true); 
}

// RENDER
suspension_frame();
visualize_landscape();

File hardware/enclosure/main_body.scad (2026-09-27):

/*
 * Open Speaker enclosure: NS-CSPGASP open-hardware rebuild
 *
 * A tall tower on roughly the original's footprint (the smaller, mains-powered
 * Insignia NS-CSPGASP is 96 x 96 x 151.6 mm):
 *   - lower section: bass chamber with the two salvaged drivers firing left and
 *     right behind round grilles, plus a tuned port (or passive radiator, or sealed)
 *   - a groove around the waist; the status light glows through it at the front
 *   - upper section: electronics bay with the clock display behind a smoked window
 *   - top plate: three buttons and two microphones, no visible fasteners
 *   - back panel: the only screwed part; it carries the port, USB-C power, the
 *     microphone mute button, and locks the top plate in place
 *
 * Every part prints in PETG without supports; orientations are in README.md.
 * OpenSCAD 2021.01 or newer. Pick a part with -D 'part="body"' etc.
 *
 * DRIVER DIMENSIONS ARE ESTIMATES until you fill in
 * hardware/speaker_specs/measurements.md; measure and edit the values below.
 */

/* [Part] */
// assembly | exploded | section | section_front | print_layout | body | deck | top_plate | back_panel | grille | clamp_ring | caps | diffuser | window | port_plug
part = "assembly";
// render colours only: light | dark
colorway = "light";

/* [Overall] */
enclosure_width = 100;      // X, left to right (NS-CSPGASP: 96)
enclosure_depth = 100;      // Y, front to back (NS-CSPGASP: 96)
enclosure_height = 160;     // Z (NS-CSPGASP: 151.6)
corner_radius = 10;
top_chamfer = 2;
bottom_chamfer = 1.5;
wall_thickness = 4;
back_thickness = 4;         // back panel
top_thickness = 3;          // top plate
waist_z = 92;               // groove around the body; the status light shines through it at the front

/* [Speakers: estimates, measure yours] */
speaker_frame_diameter = 52;    // outside of the frame / mounting flange
speaker_cone_diameter = 46;     // cone + surround; the clamp ring must not cover it
speaker_basket_diameter = 46;   // widest part behind the flange (passes through the wall)
speaker_flange_thickness = 3;
speaker_depth = 25;             // front of the flange to the back of the magnet
speaker_magnet_diameter = 30;
speaker_center_y = 50;          // from the front
speaker_center_z = 46;
// clamp: a printed ring holds the frame (works for any round driver)
// holes: screws through the frame's own holes
speaker_mount = "clamp";
speaker_hole_circle = 45;       // holes mode only
speaker_hole_count = 4;
speaker_hole_angle = 45;

/* [Grilles] */
grille_pattern = "hex";         // hex | rings
grille_thickness = 1.5;

/* [Bass] */
bass_mode = "port";             // port | passive_radiator | sealed
deck_z = 84;                    // top of the chamber
deck_thickness = 3;
port_diameter = 16;
port_wall = 2;
port_tuning_hz = 120;
radiator_frame = 55;            // passive radiator (measure yours)
radiator_cutout = 49;
radiator_hole_circle = 60;
radiator_hole_count = 4;

/* [Display] */
display_type = "oled_1_3";      // oled_1_3 | oled_2_42 | tm1637
display_center_z = 125;         // centre of the visible area
window_thickness = 1.6;         // 1/16" smoked acrylic, flush with the front: measure your sheet

/* [Status light] */
light_length = 44;
light_height = 2.4;

/* [Controls] */
button_diameter = 10;
button_pitch = 17.78;           // 7 x 2.54 mm: all three switches fit one strip of perfboard
button_y = 50;                  // row of buttons and microphones, from the front
switch_height = 4.3;            // Omron B3F-1000 (6 x 6 mm): board to the top of the plunger
cap_proud = 0.8;                // how far the caps stand above the surface
mute_x = 50;                    // microphone mute button on the back panel
mute_z = 146;

/* [Microphones] */
mic_pcb = 14;                   // INMP441 breakout, 14 x 14 mm
mic_port_diameter = 1.6;
mic_spacing = 68;

/* [Electronics] */
brain = "esp32_s3";             // esp32_s3 | pi_zero_2w
pi_origin = [18.5, 26];         // Pi Zero 2 W corner (x, y) on the deck; microSD end faces the back
standoff_height = 5;
esp32_cradle_height = 25;       // ESP32-S3: room under the board for the harness plugs
amp_board = [19.4, 17.8];       // Adafruit 3006 MAX98357A
usbc_board = [14.2, 20.4, 1.6]; // Adafruit 4090: across, along the plug, PCB thickness
usbc_x = 68;
usbc_z = 101;                   // centre of the receptacle

/* [Fit and fasteners] */
fit = 0.25;                     // clearance between printed parts
seal = 0.5;                     // compressed foam tape wherever the chamber must be airtight
insert_diameter = 4.0;          // M3 heat-set insert
insert_depth = 6;
m3_clearance = 3.4;
m3_head = 6.2;                  // countersunk
m3_pilot = 2.6;                 // M3 screw cutting its own thread in PETG
m25_pilot = 2.2;
m2_pilot = 1.7;
foot_diameter = 12.7;           // 3M Bumpon SJ5312 feet, in 1 mm recesses

/* [Rendering] */
$fn = 64;

// ---------------------------------------------------------------------------
// Derived values

W = enclosure_width;
D = enclosure_depth;
H = enclosure_height;
r = corner_radius;
w = wall_thickness;
bt = back_thickness;
tt = top_thickness;
eps = 0.01;

frame = 8;                          // how far the back panel overlaps the body
frame_t = 3;                        // body frame around the back opening
panel_x0 = r;                       // the back panel fills the flat part of the back
panel_x1 = W - r;
open_x0 = panel_x0 + frame;         // access opening
open_x1 = panel_x1 - frame;
open_z0 = w + frame;
panel_y = D - bt;                   // inside face of the back panel
inner_back = panel_y - frame_t;     // the cavity ends here beside the opening
deck_top = deck_z + deck_thickness;
plate_z = H - tt;                   // underside of the top plate

// drivers: stack from the outside face inwards
clamp = speaker_mount == "clamp";
ring_t = 2.4;
ring_od = speaker_frame_diameter + 18;
ring_screw_circle = speaker_frame_diameter + 10;
grille_d = clamp ? ring_od : max(speaker_frame_diameter, speaker_hole_circle + 7) + 6;
grille_recess = grille_thickness + 0.3;                         // grilles sit 0.3 mm below the surface
flange_front = grille_recess + (clamp ? ring_t : 2.5);          // holes mode: room for pan heads
seat_floor = flange_front + speaker_flange_thickness + seal;
boss_depth = (clamp ? flange_front : seat_floor) + 9;           // M3 x 8 screws
boss_r = grille_d/2 + fit + 2.5;

// display presets:
// [pcb_w, pcb_h, pcb_t, face_w, face_h, face_t, active_w, active_h, active_dy, window_w, window_h]
display = display_type == "oled_2_42" ? [70.9, 43.4, 1.6, 60.5, 37.0, 2.0, 55.01, 27.49, 0, 68, 40] :
          display_type == "tm1637"    ? [42.0, 24.0, 1.6, 30.0, 14.0, 7.0, 30.0, 14.0, 0, 44, 24] :
                                        [35.4, 33.5, 1.6, 34.5, 23.0, 1.1, 29.42, 14.70, 0, 52, 30];
pcb_w = display[0];
pcb_h = display[1];
pcb_t = display[2];
face_t = display[5];
active = [display[6], display[7]];
pcb_cz = display_center_z - display[8];
window = [display[9], display[10]];

cap_flange = 1.2;
cap_flange_d = button_diameter + 2.4;
switch_boss_h = switch_height + cap_flange - 0.2;               // slight preload, no rattle
rail_lip_y = w + face_t + pcb_t + fit;                          // back of the display PCB
rails_back = rail_lip_y + 1.4;
top_ledge = 2.5;
deck_ledge = 7;
deck_inset = top_ledge + fit;                                   // the deck drops in past the top ledge
led_face_y = rails_back + fit;                                  // LEDs clear the display rails as the deck goes in
led_fin_y = led_face_y + 1.9;                                   // strip + LED height in front of the fin
port_r = port_diameter / 2;

// Chamber volume (approximate) and port length (Helmholtz):
//   Fb = c / (2 pi) * sqrt(A / (V * Leff))
chamber_gross = (W - 2*w) * (inner_back - w) * (deck_z - w);
bosses = 2 * PI * pow(boss_r, 2) * (boss_depth - w) * 0.7;
drivers_in = 2 * PI * pow(speaker_basket_diameter/2, 2) * (speaker_depth - (seat_floor - flange_front)) * 0.5;
port_tube = PI * pow(port_r + port_wall, 2) * 60;
chamber_net_l = (chamber_gross - bosses - drivers_in - (bass_mode == "port" ? port_tube : 0)) / 1e6;
port_leff = PI * pow(port_r / 1000, 2) * pow(343, 2)
            / (4 * pow(PI, 2) * pow(port_tuning_hz, 2) * chamber_net_l / 1000) * 1000;
port_length = max(bt + 5, port_leff - 1.46 * port_r);           // minus both end corrections

echo(str("Outer size: ", W, " x ", D, " x ", H, " mm"));
echo(str("Chamber: ~", round(chamber_net_l * 100) / 100, " L net"));
if (bass_mode == "port")
    echo(str("Port: ", port_diameter, " mm x ", round(port_length), " mm, tuned to ~", port_tuning_hz, " Hz"));
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

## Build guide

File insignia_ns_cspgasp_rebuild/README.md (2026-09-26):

> **Archived.** This was the first plan: keep the Insignia case and drive its
> original display board from a Pi through an adapter for the ribbon cable. The
> main board turned out to be locked down, and splicing the ribbon bricked the
> unit. The project continues with new electronics and a new enclosure; see the
> [main README](../README.md). The bill of materials, the test bench for probing
> the ribbon (`BOM_POC_BENCH.md`), the mounting bracket and the probe scripts'
> `requirements.txt` from that plan are kept here for reference.

# Insignia NS-CSPGASP Rebuild (Condor Board Replacement)

This project documents the process of replacing the "brain" (Main Logic Board) of the **Insignia Voice Smart Bluetooth Speaker (NS-CSPGASP)** with a **Raspberry Pi Zero 2 W**.

## Why?
The original Google Assistant integration ("Condor" platform) often becomes unreliable or unsupported. This mod reuses the high-quality speaker, enclosure, and potentially the LED display to create a fully private, local-controlled smart speaker running:
-   Spotify Connect
-   Home Assistant (Voice Satellite)
-   AirPlay (via Shairport)

## Disclaimer
**This is an advanced hardware mod.**
-   Requires soldering.
-   Requires buying a Ribbon Cable Breakout board.
-   Involves working with power circuits.
-   **YOU DO THIS AT YOUR OWN RISK.**

## Current Status
-   [x] Teardown & Component Identification
-   [ ] Reverse Engineering Top Board (Display/Touch)
-   [ ] Designing FPC Interface
-   [ ] Final Assembly

See [HARDWARE.md](HARDWARE.md) for pinouts and wiring details.

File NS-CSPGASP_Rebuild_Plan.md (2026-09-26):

# NS-CSPGASP rebuild: plan and design decisions

How the project got here, what it is trying to do, and why the parts and software
are what they are. The build itself is in [docs/ASSEMBLY_GUIDE.md](docs/ASSEMBLY_GUIDE.md).

## History

1. **Reuse the case and display board** (archived in
   [`insignia_ns_cspgasp_rebuild/`](insignia_ns_cspgasp_rebuild/)). The idea was
   to keep the Insignia enclosure and its "Condor" top board (LED clock and touch
   controls) and drive them from a Pi through an adapter for the ribbon cable.
   The main board is locked down with secure boot, and splicing the ribbon bricked
   the unit.
2. **Teardown and new spec** (the `reverse-engineer` branch). Only the two drivers
   are worth keeping. New electronics, new enclosure.
3. **v2** (this branch). The software is rewritten as an installable package with
   a voice pipeline for Home Assistant and local models. The enclosure is
   redesigned as a tower on the smaller, mains-powered NS-CSPGASP's footprint
   (96 × 96 × 151.6 mm): left and right drivers, a bass chamber, and the clock
   display high on the front. Buttons replace the touch controls.

## Goals

- Open source, and built only from parts anyone can buy. The drivers are the only
  thing reused.
- A good Home Assistant voice speaker: wake word, voice commands, announcements.
- Speech recognition and AI models on the local network, configurable, with no
  cloud needed.
- Still a clock: the time and temperature always on the display; timers and
  alarms that work offline and survive reboots.
- Roughly the original's footprint and loudness (about 90 dB), in stereo.

## Decisions

| Topic | Decision | Why |
|---|---|---|
| Computer | Raspberry Pi Zero 2 W | Linux, Wi-Fi, enough for a wake word; small and cheap |
| Where speech runs | Wake word on the speaker, everything else on the network | Even Whisper tiny takes seconds per command on a Zero 2 W; see [docs/LOCAL_AI.md](docs/LOCAL_AI.md) |
| Wake word | microWakeWord by default; openWakeWord or a Wyoming server optional | microWakeWord is small enough for the Zero 2 W with room to spare |
| Voice pipeline | Home Assistant's Assist pipeline over its WebSocket API, or the speaker's own pipeline to Wyoming and OpenAI-compatible servers | Home Assistant users get everything from their existing pipeline; others can point at any common local server |
| On-device commands | Timers, alarms, stop, snooze and volume are handled before the pipeline | Instant, and they keep working when the network is down |
| Audio out | 2 × MAX98357A on one I2S bus; `SD` voltage selects left or right | Digital all the way to the amps, no analog noise; 3 W each into the 4 Ω drivers |
| Audio in | 2 × INMP441 on the same I2S bus | Built in, no USB; the two mics share one data line |
| Sound card | `googlevoicehat-soundcard` overlay | Plays and records on the same I2S port. `hifiberry-dac`, from the earlier plan, can only play. It claims GPIO16, so that pin stays free. |
| Sharing the sound card | ALSA `dmix`/`dsnoop` with a `Master` softvol, from [config/asound.conf](config/asound.conf) | Wake word, replies and music share the card; volume works without a hardware mixer |
| Display | 1.3" I2C OLED by default; 2.42" OLED or TM1637 optional | Shows the original's layout (big time, temperature underneath, AL/PM); the OLED is sharp behind a smoked window |
| Status light | WS2812B driven over SPI | No root access or kernel PWM needed |
| GPIO library | gpiozero with the lgpio backend | RPi.GPIO's edge detection no longer works on current kernels |
| Buttons | Physical: volume −/+, action (talk/stop/snooze), microphone mute | Touch pads were unreliable on the original |
| Enclosure | One-piece PETG body, round side grilles, shared tuned bass chamber, clamp-ring driver mounts, flush top plate, screwed back panel | See [hardware/enclosure/README.md](hardware/enclosure/README.md#design-notes) |
| Chamber | One shared, ported chamber instead of two sealed ones | More bass from small drivers; at low frequencies both play the same signal anyway |

Issues that were open on the `reverse-engineer` branch are now settled:

- **Microphones**: the internal I2S INMP441 pair everywhere; the USB microphone
  option is gone.
- **Full duplex**: a single `googlevoicehat-soundcard` overlay replaces
  `hifiberry-dac`.
- **Driver dimensions**: still to be measured. The enclosure is parametric, and
  the clamp-ring mount works whether or not the drivers have screw holes.

## Still to verify on real hardware

- The drivers' dimensions and the port tuning (120 Hz by default) against the
  real drivers.
- The right amplifier's `SD` resistor on the boards actually bought (target about
  1.0 V).
- The OLED's active-area offset on the chosen module (`display` presets in
  `main_body.scad`).
- Microphone gain and the wake-word threshold inside the finished enclosure.

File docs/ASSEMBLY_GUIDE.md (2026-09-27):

# Build guide

From an Insignia NS-CSPGASP on the bench to a working Open Speaker. Parts are in
[BOM.md](BOM.md), wiring in
[gpio_pinout.md](../hardware/schematics/gpio_pinout.md), and the enclosure in
[hardware/enclosure/README.md](../hardware/enclosure/README.md).

Everything is tested on the desk before it goes into the enclosure.

## 1. Take the drivers out of the original

1. Peel off the rubber feet and remove the screws under them, then release the
   clips around the seam with a plastic pry tool.
2. Inside is a plastic speaker box that holds both drivers, and the Condor boards
   on top of it. Unplug the speaker cables from the main board.
3. Unscrew the halves of the speaker box. The drivers sit in round seats between
   the halves, with rubber rings around them. Lift them out without touching the
   cones. If there's a passive radiator (a flat disc with a rubber surround), keep
   it too.
4. Mark each driver's + terminal (usually red, or a dot or "+" on the frame).

## 2. Measure and test the drivers

Fill in [measurements.md](../hardware/speaker_specs/measurements.md): frame
diameter, cone diameter, the widest part behind the flange, flange thickness and
depth. These go into the enclosure model (step 6).

- Resistance across the terminals: about 3.2 Ω for a 4 Ω driver.
- Polarity: touch a 1.5 V battery to the terminals, + to +. The cone should move
  outwards.

## 3. Set up the brain

The speaker has one of two brains ([which one?](../README.md#two-brains)). The
wiring is the same for both apart from the pins on the brain itself.

### ESP32-S3

Flash it before anything is wired to it. Follow
[esphome/README.md](../esphome/README.md#install): the ESPHome Device Builder in
Home Assistant builds the firmware and flashes it over USB, and after that it
updates over Wi-Fi.

### Raspberry Pi Zero 2 W

1. With [Raspberry Pi Imager](https://www.raspberrypi.com/software/), write
   **Raspberry Pi OS Lite (64-bit)**. In the settings, set the hostname
   (`open-speaker`), your Wi-Fi, a user, SSH and your time zone (the clock uses it).
2. Boot the Pi and log in: `ssh <user>@open-speaker.local`.
3. Install:

   ```sh
   sudo apt install -y git
   git clone -b v2 https://github.com/brewer-michael/ns-cspgasp-rebuild.git
   sudo ns-cspgasp-rebuild/scripts/install.sh
   sudo reboot
   ```

   The installer sets up the sound card, I2C and SPI, installs the software into
   `/opt/open-speaker`, writes `/etc/open-speaker/config.yaml` and a systemd
   service, and turns off Wi-Fi power saving. It is safe to run again to update.

## 4. Test on the desk

Wire everything on a half-size breadboard with jumper wires
([desk test parts](BOM.md#desk-test)) as in
[gpio_pinout.md](../hardware/schematics/gpio_pinout.md). Each shared line, such as
a clock that goes to both amplifiers, gets its own breadboard row. Power the brain
through the USB-C breakout, not its own USB port, so the amplifiers get their
current straight from the supply.

Whichever the brain, start with one amplifier and one driver, then add the second
amplifier. With the resistor on the right amp's `SD` pin, measure `SD` to ground:
about 1.0 V (0.77–1.4 V).

### ESP32-S3

Unplug its USB cable before you power it from the breakout. Watch its log over
Wi-Fi: **Logs** in the Device Builder, or `esphome logs esphome/open-speaker.yaml`.

- **Display and light.** The clock shows "--:--" and "net" until Home Assistant
  connects (step 5), then the time. The light is dim blue once it's ready.
- **Buttons.** − and + show "Vol 40" and so on; the back button shows "mic off".
- **Sound.** Each volume press ticks. Play something to the speaker's media player
  in Home Assistant to check both drivers.
- **Microphones.** Say "Okay Nabu": the log shows the wake word and the light turns
  green.

### Raspberry Pi Zero 2 W

**Sound.**

```sh
aplay -l                                  # the card is "sndrpigooglevoi"
speaker-test -D default -c 2 -t wav -l 1  # says "front left", "front right"
```

Check that each side says its own name.

**Microphones.**

```sh
sudo open-speaker test-mic --seconds 5    # shows the level while you talk
```

A silent channel usually means a swapped `L/R` pin or a loose `SD` wire.

**Display, LEDs, buttons.** `i2cdetect -y 1` should show the OLED at `3c`. Then
run the full check:

```sh
sudo open-speaker doctor
```

It checks the sound devices, the microphones, the wake word model, the display,
the LEDs, the GPIO pins and every server in the configuration.

## 5. Connect it to Home Assistant and your servers

**ESP32-S3:** add it in Home Assistant and choose its Assist pipeline:
[HOME_ASSISTANT.md](HOME_ASSISTANT.md#esp32-s3-speaker). The pipeline decides
which speech and language servers answer.

**Pi:** follow [HOME_ASSISTANT.md](HOME_ASSISTANT.md) (token, Assist pipeline), or
[LOCAL_AI.md](LOCAL_AI.md) to run without Home Assistant. Then:

```sh
sudo open-speaker doctor                  # everything OK?
sudo systemctl start open-speaker
journalctl -u open-speaker -f             # watch the log
```

Say **"Okay Nabu"**, wait for the chime, then try "what time is it?" or "set a
timer for one minute".

## 6. Print the enclosure

Enter your driver measurements, export and print:
[hardware/enclosure/README.md](../hardware/enclosure/README.md). Everything prints
in PETG without supports.

## 7. Build it

Follow the assembly order in the
[enclosure README](../hardware/enclosure/README.md#assembly). A few tips:

- Make the wiring harness before you start: the brain sits on the deck at the
  bottom of the head. The display (front), buttons and microphones (top plate),
  the mute button and USB-C (back panel) need about 12–15 cm of wire each.
  Female jumper housings on the brain's pins make the top plate and back panel
  removable.
- Seal the chamber well: foam tape on the deck ledge and the back frame, and hot
  glue in the deck's wire hole. Leaks make the bass weak and can whistle at the
  port.
- Test again before closing the back panel (on the Pi: `sudo open-speaker doctor`).

## Using it

| | |
|---|---|
| **Wake word** | "Okay Nabu" (change it in the configuration: `wake_word` on the ESP32-S3) |
| **Action button** (top, middle) | Tap: talk, or stop whatever is happening. When an alarm rings: tap to snooze, hold to turn it off |
| **− / +** | Volume; hold to keep changing |
| **Mute** (back) | Microphone off and on. The light turns dim red and the display says "mic off" |

**Timers and alarms.**

- **ESP32-S3.** Set timers by voice: "set a timer for 10 minutes". Home Assistant
  keeps track of them and the speaker rings. Set the alarm in Home Assistant
  (**Alarm**, **Alarm time**, **Alarm days** on the device page). It rings from the
  speaker's own clock, so it works while Home Assistant is down.
- **Pi.** The speaker handles these itself, even when your server is down: "set a
  timer for 10 minutes", "how much time is left?", "wake me up at 6:30 on
  weekdays", "what alarms do I have?", "cancel my alarm", "stop", "snooze",
  "set the volume to 4".

Everything else goes to Home Assistant or your language model: "turn on the
kitchen lights", "is the front door locked?", "how far away is the moon?".

**Display.** It always shows the time and the temperature. The volume, "mic off"
or a timer's countdown take the temperature's place for a moment. "AL" means an
alarm is set. "net" in place of the temperature means Home Assistant or your
voice servers can't be reached; alarms still ring. It dims from 22:00 to 07:00.

Clock face examples

**Light.** Dim blue: ready. Green: listening. Pulsing cyan: thinking. Pulsing blue: speaking.
Pulsing orange: alarm or timer. Dim red: microphone muted. Red: error.

## Troubleshooting

| Problem | Check |
|---|---|
| ESP32-S3: "net" on the display | Is it online in Home Assistant? Check Wi-Fi and the API key in its YAML, and the log |
| ESP32-S3: no sound | The `amp_*_pin` settings match your wiring; play something to its media player |
| ESP32-S3: wake word never triggers | The left mic's `L/R` to GND and `SD` to GPIO17; raise `mic_gain` |
| Pi: no sound card in `aplay -l` | Reboot after installing; `dtoverlay=googlevoicehat-soundcard` in `/boot/firmware/config.txt` |
| Both sides play the same, or one is silent | The `SD` voltages (step 4); left `SD` straight to 5 V |
| Crackles at high volume | Supply too weak, or the amps powered through the brain |
| Pi: microphones silent | `L/R` pins (left to GND, right to 3.3 V); `SD` of both mics to GPIO20 |
| Pi: wake word never triggers | `sudo open-speaker test-mic`: the level should rise clearly when you talk; try `audio.input.gain_db: 10` |
| Pi: wake word triggers by itself | Set `wake.threshold` a little higher |
| OLED blank | Its address is usually 0x3C (on the Pi: `i2cdetect -y 1`; set `display.oled.address`). The 0.96" type needs `driver: ssd1306` on the Pi |
| LEDs flicker or show wrong colours | The diode or level shifter from the wiring guide; on the Pi also `core_freq=250` in config.txt |
| Pi: "Authentication failed" | The token in `/etc/open-speaker/secrets.env`, then `sudo systemctl restart open-speaker` |
| Pi: "net" on the display | `sudo open-speaker doctor` shows which server can't be reached |
| Slow answers | See "Making it quick" in [LOCAL_AI.md](LOCAL_AI.md#making-it-quick) |

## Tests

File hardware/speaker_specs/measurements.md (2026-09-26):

# Speaker Measurements

**Source:** Insignia NS-CSPGASP (salvaged)
**Date:** _____________
**Measured By:** _____________

---

## Speaker Identification

| Property | Left Speaker | Right Speaker |
|---|---|---|
| Markings/Part# | | |
| Manufacturer | | |

---

## Physical Dimensions

### Outer Diameter (Mounting Flange)

```
        ┌─────────────────┐
        │    ◄─────────►  │
        │     Diameter    │
        │                 │
        │    (Speaker)    │
        │                 │
        └─────────────────┘
```

| Measurement | Left Speaker | Right Speaker |
|---|---|---|
| Outer Diameter (frame / flange) | ______ mm | ______ mm |
| Cone Diameter (cone + rubber surround) | ______ mm | ______ mm |
| Widest part behind the flange (basket) | ______ mm | ______ mm |
| Flange thickness | ______ mm | ______ mm |

### Depth (Front to Back)

```
    Front ──┬────────────────┬── Back
            │                │
            │◄── Depth ────►│
            │                │
            ├────────────────┤
            │    (Magnet)    │
            └────────────────┘
```

| Measurement | Left Speaker | Right Speaker |
|---|---|---|
| Total Depth | ______ mm | ______ mm |
| Magnet Depth | ______ mm | ______ mm |

### Mounting Holes

```
           ┌───●───────●───┐
           │               │
           │   (Speaker)   │
           │               │
           └───●───────●───┘
               ◄───────►
              Hole Spacing
```

| Measurement | Left Speaker | Right Speaker |
|---|---|---|
| # of Mounting Holes (0 if none) | | |
| Hole Diameter | ______ mm | ______ mm |
| Hole Pattern (circle dia.) | ______ mm | ______ mm |
| Screw Size (if known) | M____ | M____ |

---

## Electrical Measurements

### DC Resistance (DCR)

**Method:** Set multimeter to Ω (resistance). Touch probes to speaker terminals.

| Measurement | Left Speaker | Right Speaker |
|---|---|---|
| DC Resistance | ______ Ω | ______ Ω |

*Expected: ~3.0-3.5Ω for a 4Ω speaker, ~6-7Ω for an 8Ω speaker*

### Polarity Check

Mark the positive terminal! When a 1.5V battery is briefly touched:
- **Positive to +**: Cone moves **outward**
- **Positive to -**: Cone moves **inward**

| Speaker | + Terminal Identified | Wire Color (if any) |
|---|---|---|
| Left | [ ] Yes | |
| Right | [ ] Yes | |

---

## Calculated/Estimated Specifications

Based on measurements and typical small speaker characteristics:

| Specification | Estimated Value | Notes |
|---|---|---|
| Nominal Impedance | 4Ω / 8Ω (circle) | Based on DCR |
| Power Handling | ~3-5W | Typical for this size |
| Frequency Range | ~200Hz - 15kHz | Estimate for 2" driver |

---

## Photos

Attach or link photos of the speakers with ruler for scale:

- [ ] Front view with ruler
- [ ] Side view (depth)
- [ ] Back view (magnet/terminals)
- [ ] Mounting hole detail

Photo locations:
```
ref-images/speaker_front.jpg
ref-images/speaker_side.jpg
ref-images/speaker_back.jpg
```

---

## Enclosure Design Parameters

**Copy these values to `hardware/enclosure/main_body.scad`** (or pass them to
`export.sh` with `-D name=value`):

```openscad
speaker_frame_diameter = ______;     // outer diameter of the frame / flange
speaker_cone_diameter = ______;      // cone + surround
speaker_basket_diameter = ______;    // widest part behind the flange
speaker_flange_thickness = ______;
speaker_depth = ______;              // front of the flange to the back of the magnet
speaker_magnet_diameter = ______;

// Only if the frame has screw holes and you want to use them instead of the
// clamp ring:
// speaker_mount = "holes";
// speaker_hole_circle = ______;     // diameter of the circle through the holes
// speaker_hole_count = ______;
```

---

## Notes

_Any observations about speaker condition, wire lengths, connector types, etc._

```

```

---

## Comparison to Estimated Values

From reference photos, the speakers appeared to be approximately 52mm diameter. Compare your measurements:

| Parameter | Estimated (from photos) | Actual Measured |
|---|---|---|
| Outer Diameter | ~52mm | ______ mm |
| Depth | ~20-25mm | ______ mm |
| Impedance | 4Ω | ______ Ω |

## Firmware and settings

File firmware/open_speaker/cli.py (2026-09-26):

"""Command line: ``open-speaker run`` and helper commands for setup and testing."""

from __future__ import annotations

import argparse
import asyncio
import contextlib
import logging
import math
import os
import signal
import sys
import time
from importlib import resources
from pathlib import Path

import aiohttp
import yaml

from . import __version__
from .config import Config, ConfigError, config_to_dict, load_config
from .const import DEFAULT_CONFIG_PATH

_LOGGER = logging.getLogger("open_speaker")


def _setup_logging(level: str) -> None:
    logging.basicConfig(
        level=getattr(logging, level.upper(), logging.INFO),
        format="%(asctime)s %(levelname)-7s %(name)s: %(message)s",
        datefmt="%H:%M:%S",
    )


def load_secrets(path: Path) -> None:
    """Read NAME=value lines from the secrets file next to the configuration.

    The service gets these from systemd; this lets ``sudo open-speaker doctor``
    and the other commands see them too. Values already in the environment win.
    """
    try:
        lines = path.read_text().splitlines()
    except OSError:
        return
    for line in lines:
        name, sep, value = line.strip().partition("=")
        name, value = name.strip(), value.strip()
        if not sep or not name or name.startswith("#"):
            continue
        if len(value) >= 2 and value[0] == value[-1] and value[0] in "'\"":
            value = value[1:-1]
        os.environ.setdefault(name, value)


def _load(args: argparse.Namespace) -> Config:
    try:
        return load_config(args.config)
    except ConfigError as err:
        print(f"Configuration error: {err}", file=sys.stderr)
        sys.exit(2)


# ---------------------------------------------------------------------------


async def _run(config: Config) -> None:
    from .factory import build_speaker

    async with aiohttp.ClientSession() as session:
        speaker = build_speaker(config, session)
        loop = asyncio.get_running_loop()
        for sig in (signal.SIGINT, signal.SIGTERM):
            with contextlib.suppress(NotImplementedError):
                loop.add_signal_handler(sig, speaker.request_stop)
        await speaker.run()


def cmd_run(args: argparse.Namespace) -> None:
    config = _load(args)
    _setup_logging("DEBUG" if args.debug else config.log_level)
    _LOGGER.info("Open Speaker %s starting (%s mode)", __version__, config.pipeline.mode)
    asyncio.run(_run(config))


def cmd_check_config(args: argparse.Namespace) -> None:
    config = _load(args)
    print(yaml.safe_dump(config_to_dict(config), sort_keys=False).rstrip())
    print(f"\n{args.config}: OK", file=sys.stderr)


def cmd_example_config(args: argparse.Namespace) -> None:
    text = resources.files("open_speaker").joinpath("data/config.example.yaml").read_text()
    sys.stdout.write(text)


def cmd_doctor(args: argparse.Namespace) -> None:
    from .doctor import run_doctor

    _setup_logging("DEBUG" if args.debug else "WARNING")
    sys.exit(asyncio.run(run_doctor(Path(args.config))))


async def _test_speaker(config: Config, speak: str | None) -> None:
    from .audio.playback import AudioPlayer, PcmFormat
    from .audio.sounds import load_sound

    player = AudioPlayer(config.audio.output)
    for name in ("wake", "done", "timer"):
        sound = load_sound(f"builtin:{name}")
        assert sound is not None
        print(f"Playing {name} sound...")
        await player.play_pcm(sound.pcm, PcmFormat(sound.rate))
        await asyncio.sleep(0.3)
    if speak:
        await _say(config, speak)


def cmd_test_speaker(args: argparse.Namespace) -> None:
    config = _load(args)
    _setup_logging("DEBUG" if args.debug else "WARNING")
    asyncio.run(_test_speaker(config, args.say))


async def _test_mic(config: Config, seconds: float, save: str | None) -> None:
    from .audio.capture import Microphone
    from .audio.pcm import rms_dbfs, wav_bytes
    from .const import SAMPLE_RATE

    mic = Microphone(config.audio.input)
    print(f"Recording {seconds:.0f} s from {config.audio.input.device!r}; speak now...")
    recorded = bytearray()
    start = time.monotonic()
    async for chunk in mic.chunks():
        recorded += chunk
        level = rms_dbfs(chunk)
        width = 0 if math.isinf(level) else max(0, int((level + 70) / 70 * 50))
        print(f"\r{level:6.1f} dBFS |{'#' * width:<50}|", end="", flush=True)
        if time.monotonic() - start >= seconds:
            break
    await mic.close()
    peak = rms_dbfs(bytes(recorded))
    print(f"\nAverage level {peak:.1f} dBFS.")
    if peak < -60:
        print("That is very quiet: check the microphone wiring, L/R pins and audio.input.channel.")
    if save:
        Path(save).write_bytes(wav_bytes(bytes(recorded), SAMPLE_RATE))
        print(f"Saved {save}")


def cmd_test_mic(args: argparse.Namespace) -> None:
    config = _load(args)
    _setup_logging("DEBUG" if args.debug else "WARNING")
    asyncio.run(_test_mic(config, args.seconds, args.save))


async def _say(config: Config, text: str) -> None:
    from .audio.playback import AudioPlayer
    from .factory import create_homeassistant, create_pipeline

    async with aiohttp.ClientSession() as session:
        ha = create_homeassistant(config, session)
        pipeline = create_pipeline(config, session, ha)
        audio = await pipeline.speak(text, config.language)
        if audio is not None:
            await AudioPlayer(config.audio.output).play(audio)
        if ha is not None:
            await ha.close()


def cmd_say(args: argparse.Namespace) -> None:
    config = _load(args)
    _setup_logging("DEBUG" if args.debug else "WARNING")
    asyncio.run(_say(config, " ".join(args.text)))


async def _ask(config: Config, text: str, speak: bool) -> None:
    from .audio.playback import AudioPlayer
    from .factory import create_homeassistant, create_pipeline
    from .intents import recognize
    from .pipeline import Conversation

    intent = recognize(text) if config.pipeline.local_intents else None
    if intent is not None:
        print(f"(handled on the speaker by the running service: {intent})")
        return
    async with aiohttp.ClientSession() as session:
        ha = create_homeassistant(config, session)
        pipeline = create_pipeline(config, session, ha)
        reply = await pipeline.respond(text, Conversation(config.language))
        print(reply.text or "(no spoken reply)")
        if speak and reply.audio is not None:
            await AudioPlayer(config.audio.output).play(reply.audio)
        if ha is not None:
            await ha.close()


def cmd_ask(args: argparse.Namespace) -> None:
    config = _load(args)
    _setup_logging("DEBUG" if args.debug else "WARNING")
    asyncio.run(_ask(config, " ".join(args.text), not args.quiet))


# ---------------------------------------------------------------------------


def build_parser() -> argparse.ArgumentParser:
    parser = argparse.ArgumentParser(
        prog="open-speaker",
        description="Open-hardware smart speaker and alarm clock for Home Assistant.",
    )
    parser.add_argument("--version", action="version", version=f"%(prog)s {__version__}")
    parser.add_argument(
        "-c", "--config", default=DEFAULT_CONFIG_PATH, help=f"default: {DEFAULT_CONFIG_PATH}"
    )
    parser.add_argument("--debug", action="store_true", help="verbose logging")
    sub = parser.add_subparsers(dest="command")

    sub.add_parser("run", help="run the speaker (default)").set_defaults(func=cmd_run)
    sub.add_parser("check-config", help="validate and print the effective configuration")
    sub.choices["check-config"].set_defaults(func=cmd_check_config)
    sub.add_parser("example-config", help="print a commented example configuration")
    sub.choices["example-config"].set_defaults(func=cmd_example_config)
    sub.add_parser("doctor", help="check hardware, audio devices and servers")
    sub.choices["doctor"].set_defaults(func=cmd_doctor)

    speaker = sub.add_parser("test-speaker", help="play test sounds")
    speaker.add_argument("--say", help="also speak this text through the voice pipeline")
    speaker.set_defaults(func=cmd_test_speaker)

    mic = sub.add_parser("test-mic", help="show microphone levels")
    mic.add_argument("--seconds", type=float, default=5.0)
    mic.add_argument("--save", help="write the recording to this WAV file")
    mic.set_defaults(func=cmd_test_mic)

    say = sub.add_parser("say", help="speak text through the voice pipeline")
    say.add_argument("text", nargs="+")
    say.set_defaults(func=cmd_say)

    ask = sub.add_parser("ask", help="send a typed request to the assistant")
    ask.add_argument("text", nargs="+")
    ask.add_argument("-q", "--quiet", action="store_true", help="print the reply only")
    ask.set_defaults(func=cmd_ask)
    return parser


def main(argv: list[str] | None = None) -> None:
    parser = build_parser()
    args = parser.parse_args(argv)
    load_secrets(Path(args.config).with_name("secrets.env"))
    func = getattr(args, "func", cmd_run)
    func(args)


if __name__ == "__main__":  # pragma: no cover
    main()

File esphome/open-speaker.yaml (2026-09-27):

# Open Speaker: the ESP32-S3 brain.
#
# The same speaker as the Raspberry Pi build: two MAX98357A amplifiers, two INMP441
# microphones, a 1.3" SH1106 OLED clock, three WS2812B status LEDs and four buttons.
# The wake word runs on the ESP32-S3; Home Assistant's Assist pipeline does the
# rest. Wiring: hardware/schematics/gpio_pinout.md. Setup: esphome/README.md.
#
# Flash this file as it is, or use it as a package from your own configuration and
# change the substitutions below there.

substitutions:
  name: open-speaker
  friendly_name: Open Speaker
  # okay_nabu, hey_jarvis, hey_mycroft or alexa
  wake_word: okay_nabu
  # The temperature on the clock. For a weather entity keep the attribute; for a
  # sensor entity set temperature_attribute to "".
  temperature_entity: weather.forecast_home
  temperature_attribute: temperature
  temperature_unit: "°"
  clock_24h: "false"
  # The display and the status light dim between these hours
  night_start_hour: "22"
  night_end_hour: "7"
  # Microphone gain for the wake word and voice commands, 1-64
  mic_gain: "4"
  # Pins on the ESP32-S3-DevKitC-1, all on its J1 header
  amp_lrclk_pin: GPIO4
  amp_bclk_pin: GPIO5
  amp_dout_pin: GPIO6
  led_pin: GPIO7
  i2c_sda_pin: GPIO8
  i2c_scl_pin: GPIO9
  volume_up_pin: GPIO11
  volume_down_pin: GPIO12
  action_pin: GPIO13
  mute_pin: GPIO14
  mic_lrclk_pin: GPIO15
  mic_bclk_pin: GPIO16
  mic_din_pin: GPIO17
  font_file: "gfonts://Roboto@700"
  # The sound files, from this repository so that the file also works as a remote
  # package. To build from a local copy: esphome -s sounds sounds ...
  sounds: https://raw.githubusercontent.com/brewer-michael/ns-cspgasp-rebuild/v2/esphome/sounds

esphome:
  name: ${name}
  friendly_name: ${friendly_name}
  min_version: 2026.9.0
  project:
    name: brewer-michael.open-speaker
    version: "2.0.0"
  on_boot:
    priority: -100
    then:
      - script.execute: update_night
      - script.execute: update_light

esp32:
  board: esp32-s3-devkitc-1
  flash_size: 8MB
  cpu_frequency: 240MHz
  framework:
    type: esp-idf
    sdkconfig_options:
      # recommended for micro_wake_word on the S3
      CONFIG_ESP32S3_DATA_CACHE_64KB: "y"
      CONFIG_ESP32S3_DATA_CACHE_LINE_64B: "y"
      CONFIG_ESP32S3_INSTRUCTION_CACHE_32KB: "y"

psram:
  mode: octal
  speed: 80MHz

logger:

api:
  id: api_server
  actions:
    # For Home Assistant automations: esphome.<device>_ring_alarm
    - action: ring_alarm
      then:
        - script.execute:
            id: ring
            kind: 2
    - action: stop_ringing
      then:
        - script.stop: snooze
        - script.execute: stop_ringing

ota:
  - platform: esphome

wifi:
  # Without Wi-Fi details the speaker opens a hotspot to set them; Improv over
  # USB works too (web.esphome.io)
  ap: {}

captive_portal:

improv_serial:

dashboard_import:
  package_import_url: github://brewer-michael/ns-cspgasp-rebuild/esphome/open-speaker.yaml@v2

i2c:
  sda: ${i2c_sda_pin}
  scl: ${i2c_scl_pin}
  frequency: 400kHz

globals:
  # 0 idle, 1 listening, 2 thinking, 3 speaking, 4 error
  - id: assistant_phase
    type: int
    initial_value: "0"
  # 0 nothing, 1 a timer, 2 the alarm
  - id: ringing
    type: int
    initial_value: "0"
  - id: ring_started
    type: uint32_t
    initial_value: "0"
  # a value that replaces the temperature for a moment (volume, mic on/off)
  - id: swap_text
    type: std::string
    initial_value: '""'
  - id: swap_until
    type: uint32_t
    initial_value: "0"
  - id: night
    type: bool
    initial_value: "false"

time:
  - platform: homeassistant
    id: ha_time
    on_time_sync:
      then:
        - script.execute: update_night
    on_time:
      - seconds: 0
        then:
          - script.execute: update_night

sensor:
  - platform: homeassistant
    id: outdoor_temperature
    entity_id: ${temperature_entity}
    attribute: ${temperature_attribute}
    internal: true

# ---------------------------------------------------------------------------
# Audio: microphones on one I2S bus, amplifiers on the other

i2s_audio:
  - id: i2s_mics
    i2s_lrclk_pin: ${mic_lrclk_pin}
    i2s_bclk_pin: ${mic_bclk_pin}
  - id: i2s_amps
    i2s_lrclk_pin: ${amp_lrclk_pin}
    i2s_bclk_pin: ${amp_bclk_pin}

microphone:
  # The left microphone (L/R to GND). The right one is used by the Pi build.
  - platform: i2s_audio
    id: mics
    i2s_audio_id: i2s_mics
    adc_type: external
    i2s_din_pin: ${mic_din_pin}
    pdm: false
    sample_rate: 16000
    bits_per_sample: 32bit
    channel: left
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

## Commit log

2026-01-17 Archive plan for reverse engineering
    [MOUNTING_BRACKET.scad]
2026-09-26 Complete teardown and spec rewrite
    [main_body.scad]
2026-09-26 Redesign the enclosure as a two-speaker tower
    A 100 x 100 x 160 mm tower on roughly the NS-CSPGASP's footprint: a bass
    chamber with the salvaged drivers firing left and right behind round press-fit
    grilles, a waist groove the status light shines through, the clock display
    behind a flush smoked window, and a top plate with three buttons and two
    microphones held by tongues instead of screws. The back panel is the only
    screwed part; it carries the tuned port (or a passive radiator, or none),
    USB-C power and the microphone mute button.
    Drivers mount from outside with a clamp ring, so drivers without screw holes
    work too. Every part prints in PETG without supports. Clearances and the
    insertion p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
    [main_body.scad]
2026-09-26 Replace the firmware with the open_speaker package
    An asyncio daemon for the Pi Zero 2 W: on-device wake word (microWakeWord by
    default, openWakeWord, or a Wyoming server), with speech-to-text, the language
    model and text-to-speech on the local network, either through a Home
    Assistant Assist pipeline or directly against Wyoming and OpenAI-compatible
    servers (Ollama, llama.cpp, faster-whisper, Piper).
    Timers, alarms and volume are handled on the speaker and survive reboots. The
    display shows the time and temperature and swaps in the volume for a moment,
    like the original. Buttons use gpiozero, the WS2812 LEDs are driven over SPI
    without root, and a small REST API lets Home Assistant make ann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
    [api.py, app.py, buttons.py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]
2026-09-26 Add the installer, a LAN model server stack and v2 documentation
    scripts/install.sh sets up a Raspberry Pi: the googlevoicehat-soundcard
    overlay for full-duplex I2S, I2C and SPI, an ALSA configuration that shares
    the card and adds Master and Music volume controls, a service user, a
    virtualenv in /opt/open-speaker, /etc/open-speaker with a secrets file, and
    the systemd service. It turns off Wi-Fi power saving and is safe to re-run.
    server/docker-compose.yml runs Whisper, Piper and Ollama (and optionally
    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
    [MOUNTING_BRACKET.scad]
2026-09-26 Understand more alarm phrasings; survive a malformed timers file
    Found while writing tests: "twenty five past seven", "the 7 o'clock alarm",
    "every weekday" and "on mondays and wednesdays" are now understood, "is there
    an alarm set" is a question rather than a new alarm, and "for 10 minutes" is
    no longer read as a clock time. A timers file that is valid JSON but the wrong
    shape is logged and ignored instead of stopping the speaker from starting.
    Also adds a rendered example of the clock face to the README and build guide.
    Claude-Session: https://claude.ai/code/session_01XTqiLJMtKEvdiCWSafvxVC
    [intents.py, timers.py]
2026-09-26 Add tests for configuration, intents, timers, PCM and VAD
    670 tests: configuration loading, environment variables and every validation
    rule; parametrized tables of timer, alarm, stop, snooze and volume phrasings;
    the scheduler with a fake clock, including repeats, snooze, missed alarms and
    persistence; PCM conversions and WAV round trips; the energy detector and the
    voice command segmenter.
    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
    [test_config.py, test_intents.py, test_pcm.py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]
2026-09-26 Find timers by length, more alarm questions, reject LEDs on SPI1
    "Cancel the 5 minute timer" now finds the timer that was set for five
    minutes when no timer has that name. "Is my alarm set", "have I set an
    alarm" and "did I set an alarm" are questions, not requests for a new alarm.
    status_leds.spi_bus: 1 is refused because SPI1 shares GPIO19-21 with the I2S
    audio.
    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
2026-09-26 Test the speaker, API, CLI and factory; fix four bugs they found
    217 tests. The Speaker runs against fake microphones, players, pipelines,
    wake engine, display, LEDs, buttons and Home Assistant with a fake clock:
    conversations and follow-ups, on-device commands, ringing, snooze, buttons,
    the display's swapped values, announcements with ducking, and start-up when
    parts fail. The HTTP API is served on localhost and every route is called;
    the CLI and the factory are covered in both pipeline modes.
    Fixes:
    - A TM1637 display never started: gpiozero's ensure_pin_factory() returns
    None, so the driver now reads Device.pin_factory after calling it.
    - A temperature sensor reporting nan or inf stopp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
    [api.py, app.py, test_api.py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]
2026-09-26 Test the Wyoming, OpenAI-compatible and Home Assistant clients
    170 tests against fake servers on localhost: the Wyoming wake word, STT and
    TTS clients (streaming, errors, dropped connections, reconnect backoff), the
    OpenAI-compatible STT, TTS and language model agent (history, cleanup for
    speech, errors), the agent chain, the Home Assistant REST and WebSocket
    client including Assist pipeline runs, and both voice pipelines.
    - A connection reset while disconnecting hid the Wyoming STT and TTS errors.
    - A reply that isn't JSON now raises SttError/AgentError, so the agent chain
    falls through to the next agent instead of failing.
    - The Home Assistant WebSocket is closed when the first m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
    [homeassistant.py, test_homeassistant.py, test_openai_compat.py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]
2026-09-26 Home Assistant client: no queue left behind by a stopped run
    Cancelling a pipeline run registered a reply queue for the unsubscribe
    message that was never removed, so every interrupted conversation left one
    behind. The unsubscribe now gets an id without a queue. Also pass ssl=True
    rather than the deprecated ssl=None when certificates are verified.
    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
2026-09-26 Show "net" when offline; "turn off my alarm" silences a ringing alarm
    - The temperature slot shows "net" while Home Assistant or the voice servers
    can't be reached, like the original's network indicator. A running timer
    or a swapped-in value still comes first.
    - "Turn off my alarm" while an alarm rings now silences it and keeps a
    repeating alarm for next time. It used to cancel the next scheduled alarm
    and leave the ringing one going. Naming a time or "all" still cancels.
    - The commands read the secrets.env next to the configuration, so
    "sudo open-speaker doctor" sees the token the service gets from systemd.
    Values already in the environment win.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
    [app.py, cli.py, test_app.py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]
2026-09-26 Enclosure README: say exactly what was checked
    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
2026-09-26 Test the hardware drivers, the display and audio I/O
    173 tests: buttons on gpiozero's mock pins (press, release, short and long
    press, repeat), the TM1637 bit-banged protocol decoded from the pin
    transitions, the OLED init sequences and page packing, the WS2812 SPI
    encoding and status animations, the volume LED, the clock face on the OLED
    and TM1637 renderers, the display loop, and recording and playback through
    stand-in subprocesses.
    - A refresh requested while the display was drawing was lost; the refresh
    flag is now cleared before the state is read.
    - When the recorder's output ends, wait briefly for it to exit so its exit
    code is kept.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
    [test_audio_io.py, test_hardware.py, test_ui.py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]
2026-09-26 Stop playback at once even when the audio source stalls
    stop() killed the player but play_stream kept waiting for the source's next
    chunk, so if a text-to-speech server stalled mid-sentence, the action button
    or "stop" did nothing until it sent more or timed out. The chunks are now fed
    from a task that stop() cancels. Cancelling the caller still cancels
    playback as before.
    When the player exits early, wait briefly for it before terminating it so its
    real exit code is logged.
    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
    [test_audio_io.py]
2026-09-26 Source every part in the BOM and fit the enclosure to it
    The bill of materials now names a specific product and store for every
    part, with its pack price and what one speaker uses, checked on
    26 September 2026. Prices that could not be confirmed are marked as
    estimates. About $87 of parts per speaker, $227 for a first build that
    buys whole packs.
    The enclosure now matches the parts chosen:
    - switch_height 4.3 for the Omron B3F-1000 switches
    - window_thickness 1.6 for 1/16" smoked acrylic
    - feet recesses for 12.7 mm 3M Bumpon SJ5312 (new foot_diameter)
    All 35 collision checks give the same results as before. The renders are
    refreshed. The enclosure README and the build guide name the same p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
    [main_body.scad]
2026-09-26 BOM: mark subtotals that include estimates
    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
2026-09-26 Add a shopping list page for the parts
    docs/shopping-list.html opens straight from a clone, with no network
    requests of its own. It lists every part with the store it was priced at,
    other stores that carry it, and searches at Google Shopping, Amazon, eBay,
    AliExpress, DigiKey and others to compare prices. It works out what to
    buy for any number of speakers, groups the parts by category or by store,
    remembers which parts are ticked off, and copies the remaining list as
    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
2026-09-27 Add an ESPHome configuration for an ESP32-S3 brain
    The Pi Zero 2 W is hard to buy, so the speaker can now run on an
    ESP32-S3-DevKitC-1 (N8R8) with ESPHome instead. The rest of the hardware
    stays the same.
    esphome/open-speaker.yaml: microWakeWord on the speaker and Home
    Assistant's Assist pipeline for the rest; stereo out through both
    MAX98357As with ducking; the clock face with the temperature slot
    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
2026-09-27 Enclosure: a brain option, with a cradle for the ESP32-S3
    brain = "esp32_s3" (default) or "pi_zero_2w". The DevKitC-1 sits pins
    down on a printed cradle that screws to the Pi's standoffs, leaving room
    underneath for the harness plugs, with its USB ports towards the back
    opening. The model checks and the renders cover the new part.
    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
    [main_body.scad]
2026-09-27 Document both brains: wiring, BOM, shopping list and guides
    - README: what each brain does and costs, and how to start with either.
    - gpio_pinout.md: a pin table per brain; the parts wire the same way.
    - BOM and shopping list: a section per brain, with a switch on the page
    and a speaker total for each. check_bom.py checks those totals too.
    - Assembly guide and Home Assistant guide: steps for each brain.
    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
2026-09-27 CI: build the ESPHome configuration and check both brains
    - New esphome job: validates and compiles esphome/open-speaker.yaml with
    ESPHome 2026.9.0, using the sounds from the checkout.
    - firmware job: the ESPHome sounds must match the firmware's.
    - enclosure job: the model with the Pi brain must pass its checks too.
    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
2026-09-27 ESPHome: fix the night-mode script's build
    A local variable named night hid the night global that id(night)
    refers to, so the lambda didn't compile.
    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
    [open-speaker.yaml]
